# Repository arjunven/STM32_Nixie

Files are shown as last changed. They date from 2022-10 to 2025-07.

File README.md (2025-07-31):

# STM32 and USB-C Based Nixie Clock
A [Nixie](http://en.wikipedia.org/wiki/Nixie_tube) clock that's powered by USB-C and based on a STM32 microcontroller. Designed schematic, layout, and firmware from scratch! Fun mix of retro tech with modern electronics. Main Features:
  - Custom 5V to 180V boost converter that operates in discontinous conduction mode to power the Nixie tubes
  - USB-C Power input + bootloader
  - Push button dial that's used to set time and interface with the menu
  - Used high voltage shift registers to run the tube display
  - STM32F100 micro controller with abysmal flash storage ... because that's all that was in stock during the great covid parts shortage of 2021 when I started this project 

## Mostly Finished Product

 
  - Still would like to add a walnut enclosure and a nice wodden knob for the push button dial
  - 80/20 rule in full force

## Layout




- 4 Layer board

## Schematics
### 5V to 180V Boost Converter


### Full Schematics
[Full Schematics here
](https://github.com/arjunven/STM32_Nixie/blob/main/pcb/outputs/STM32_Nixie_Schematics.pdf
)

## Bringup/Development



- Bring up of HV shift register driver with assistance from Merlin

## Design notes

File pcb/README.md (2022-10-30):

View this project on [CADLAB.io](https://cadlab.io/project/26133). 

# STM32_Nixie
 STM32 based Nixie clock with USB C 5V input.

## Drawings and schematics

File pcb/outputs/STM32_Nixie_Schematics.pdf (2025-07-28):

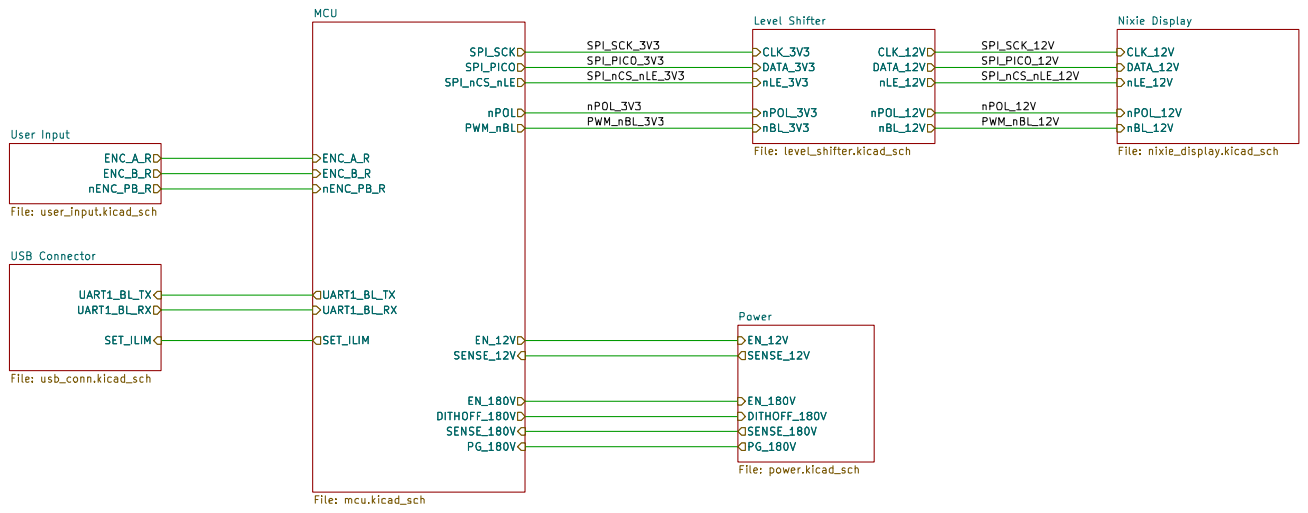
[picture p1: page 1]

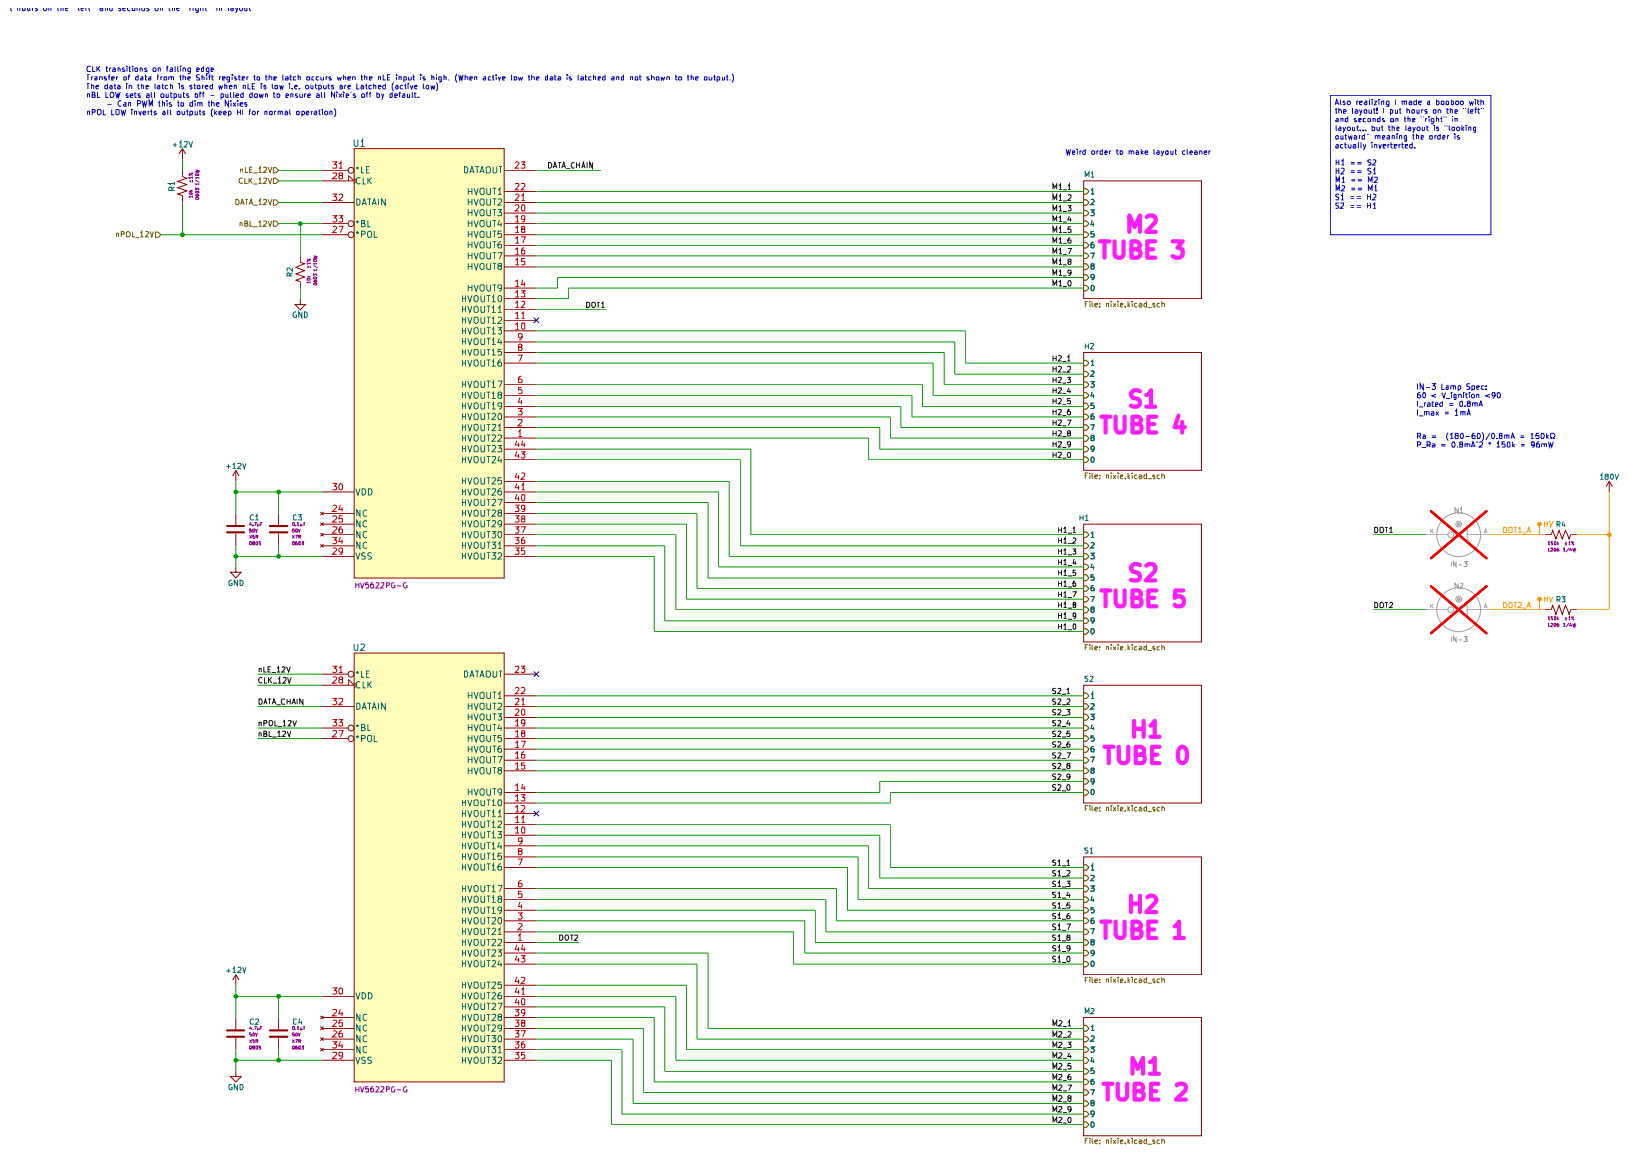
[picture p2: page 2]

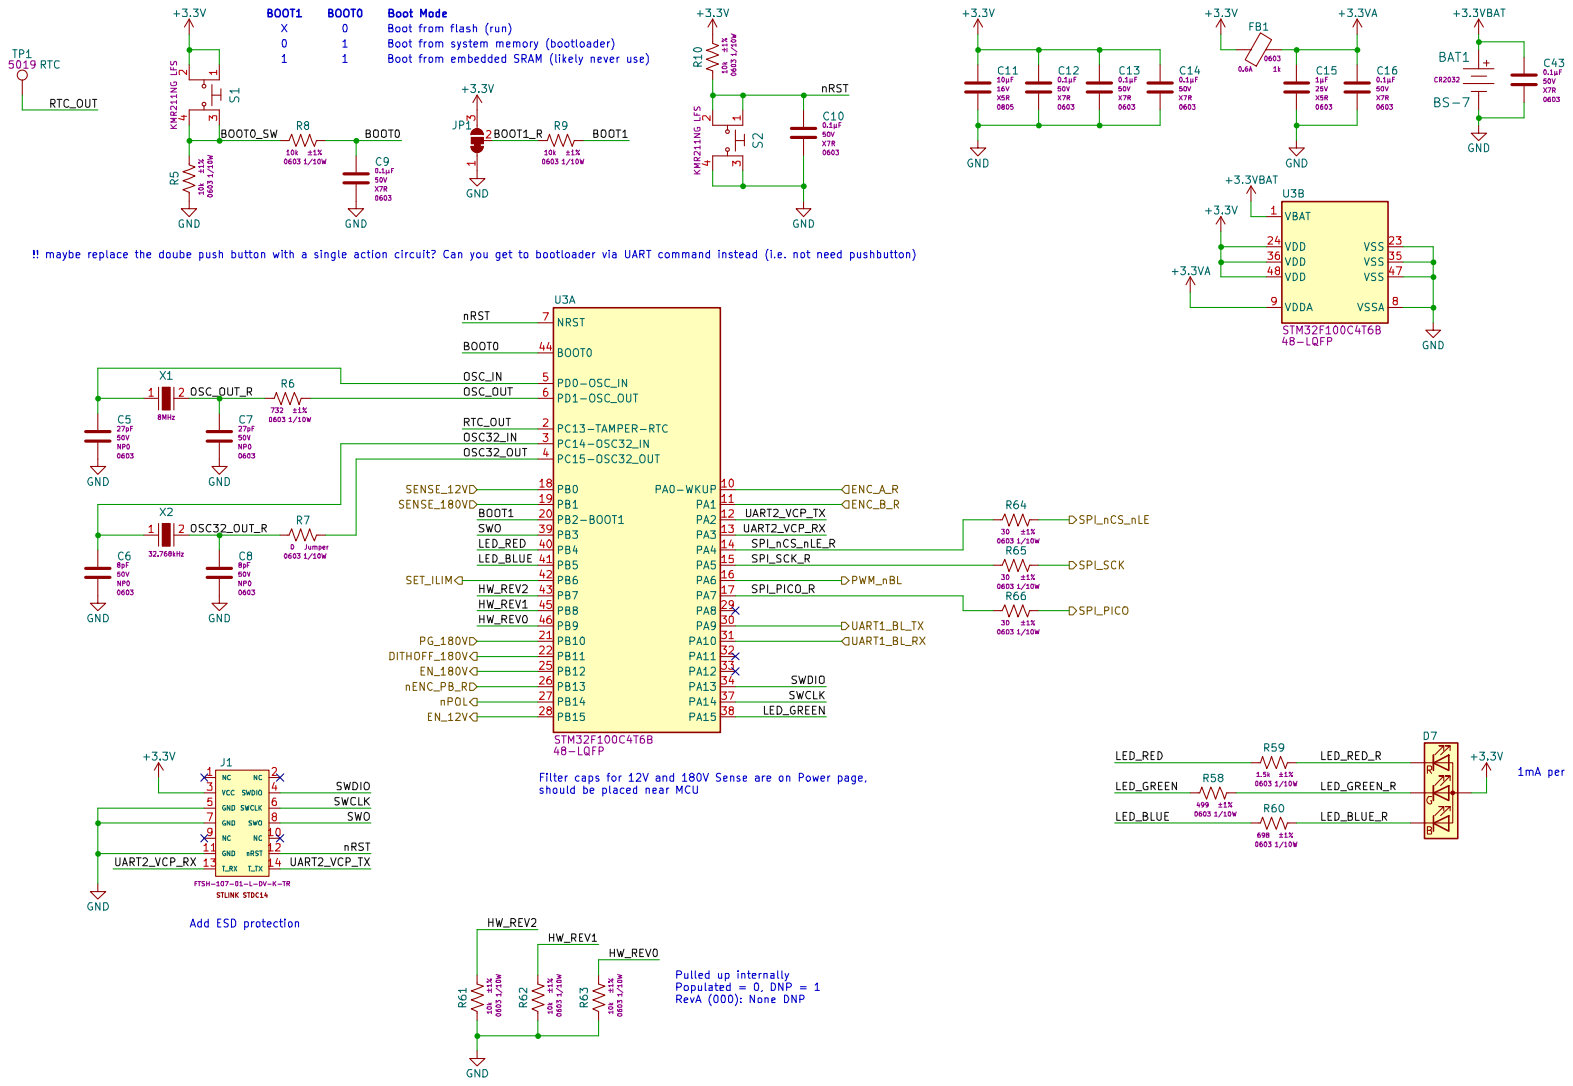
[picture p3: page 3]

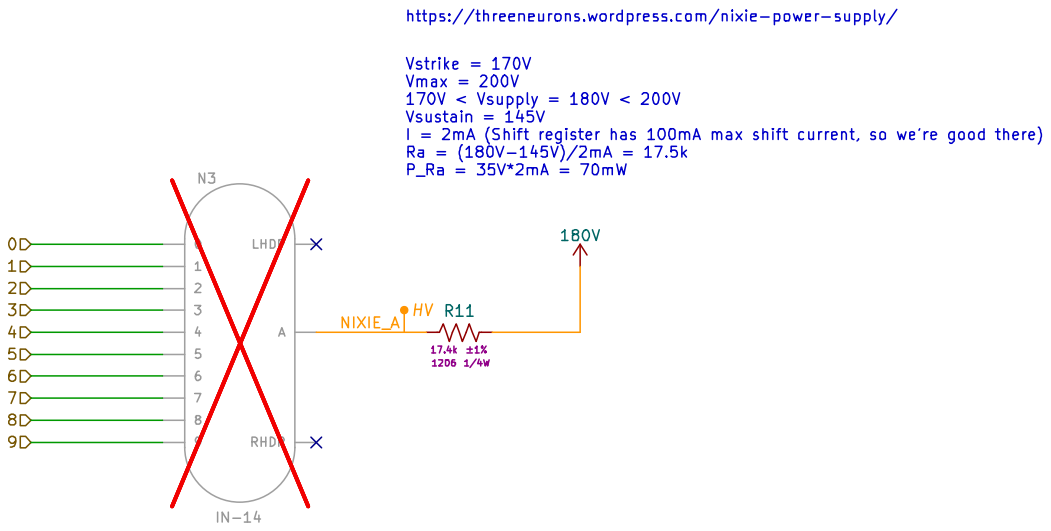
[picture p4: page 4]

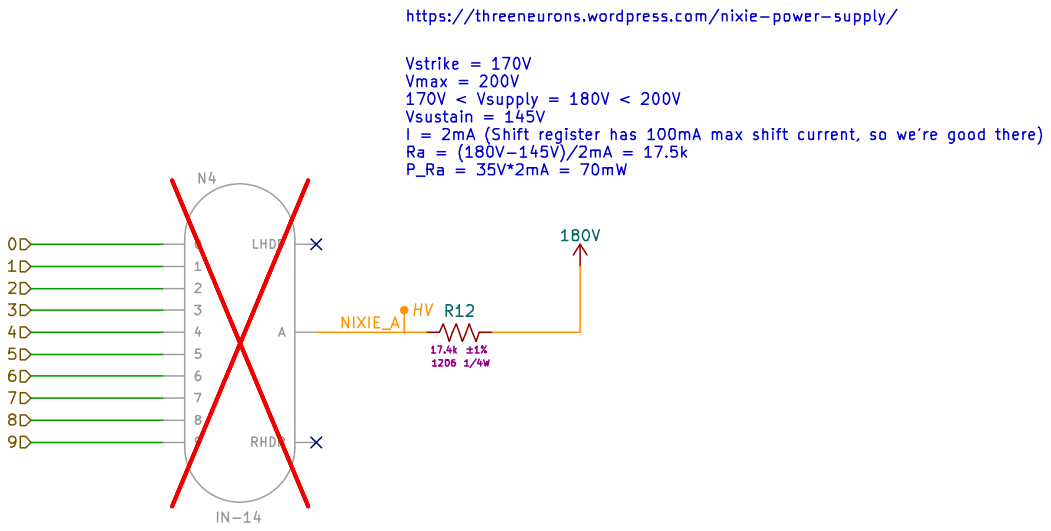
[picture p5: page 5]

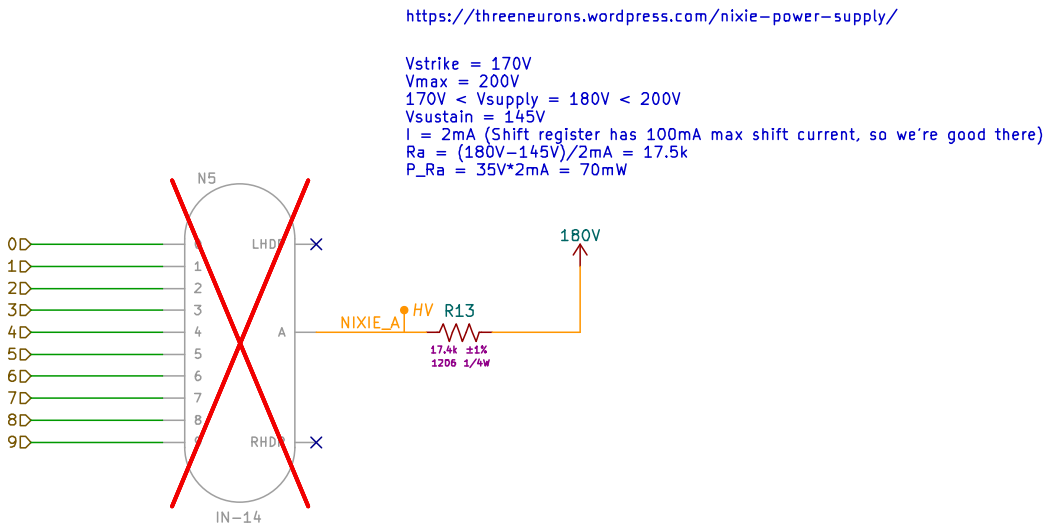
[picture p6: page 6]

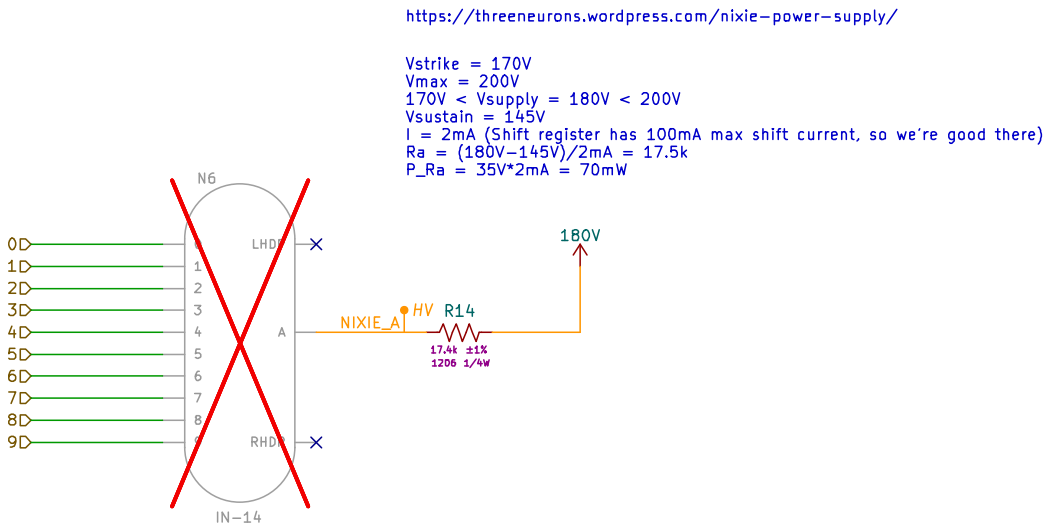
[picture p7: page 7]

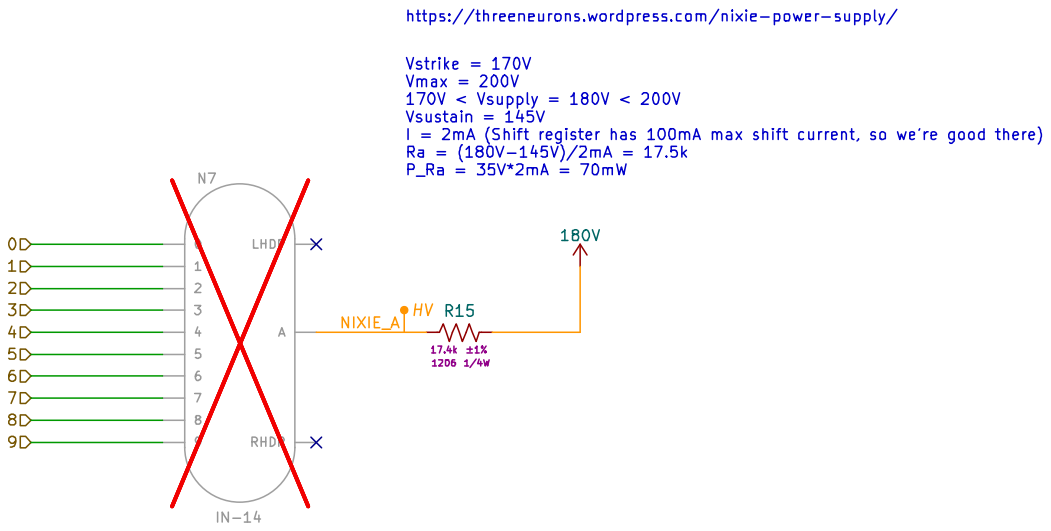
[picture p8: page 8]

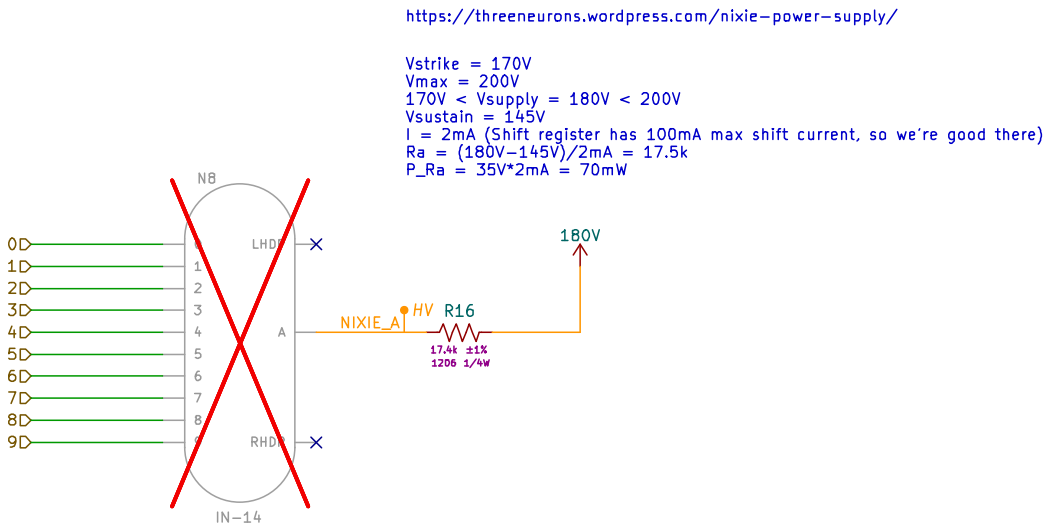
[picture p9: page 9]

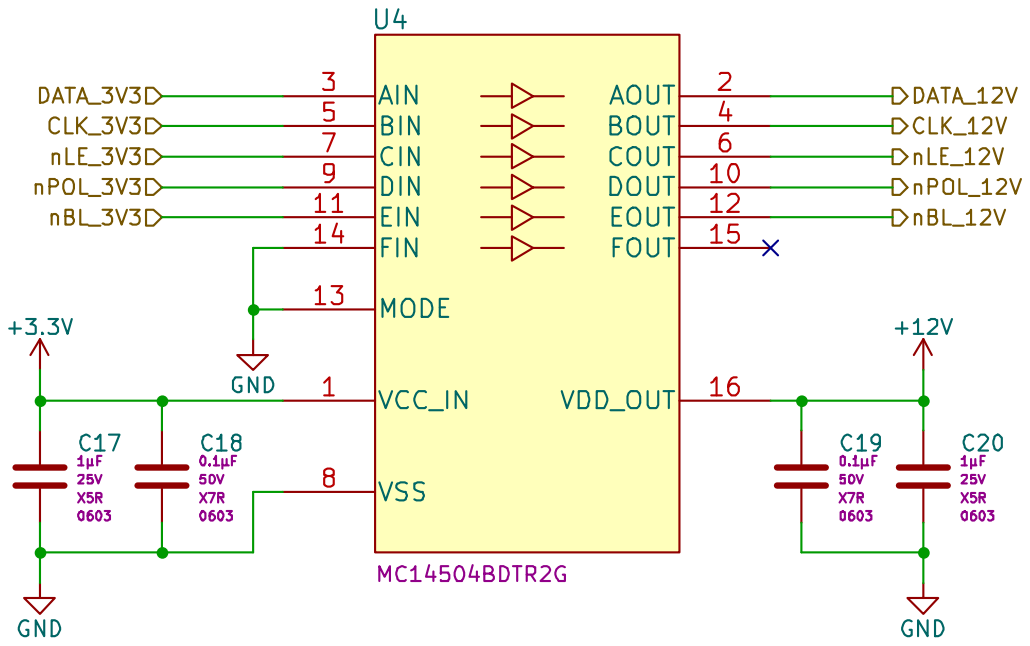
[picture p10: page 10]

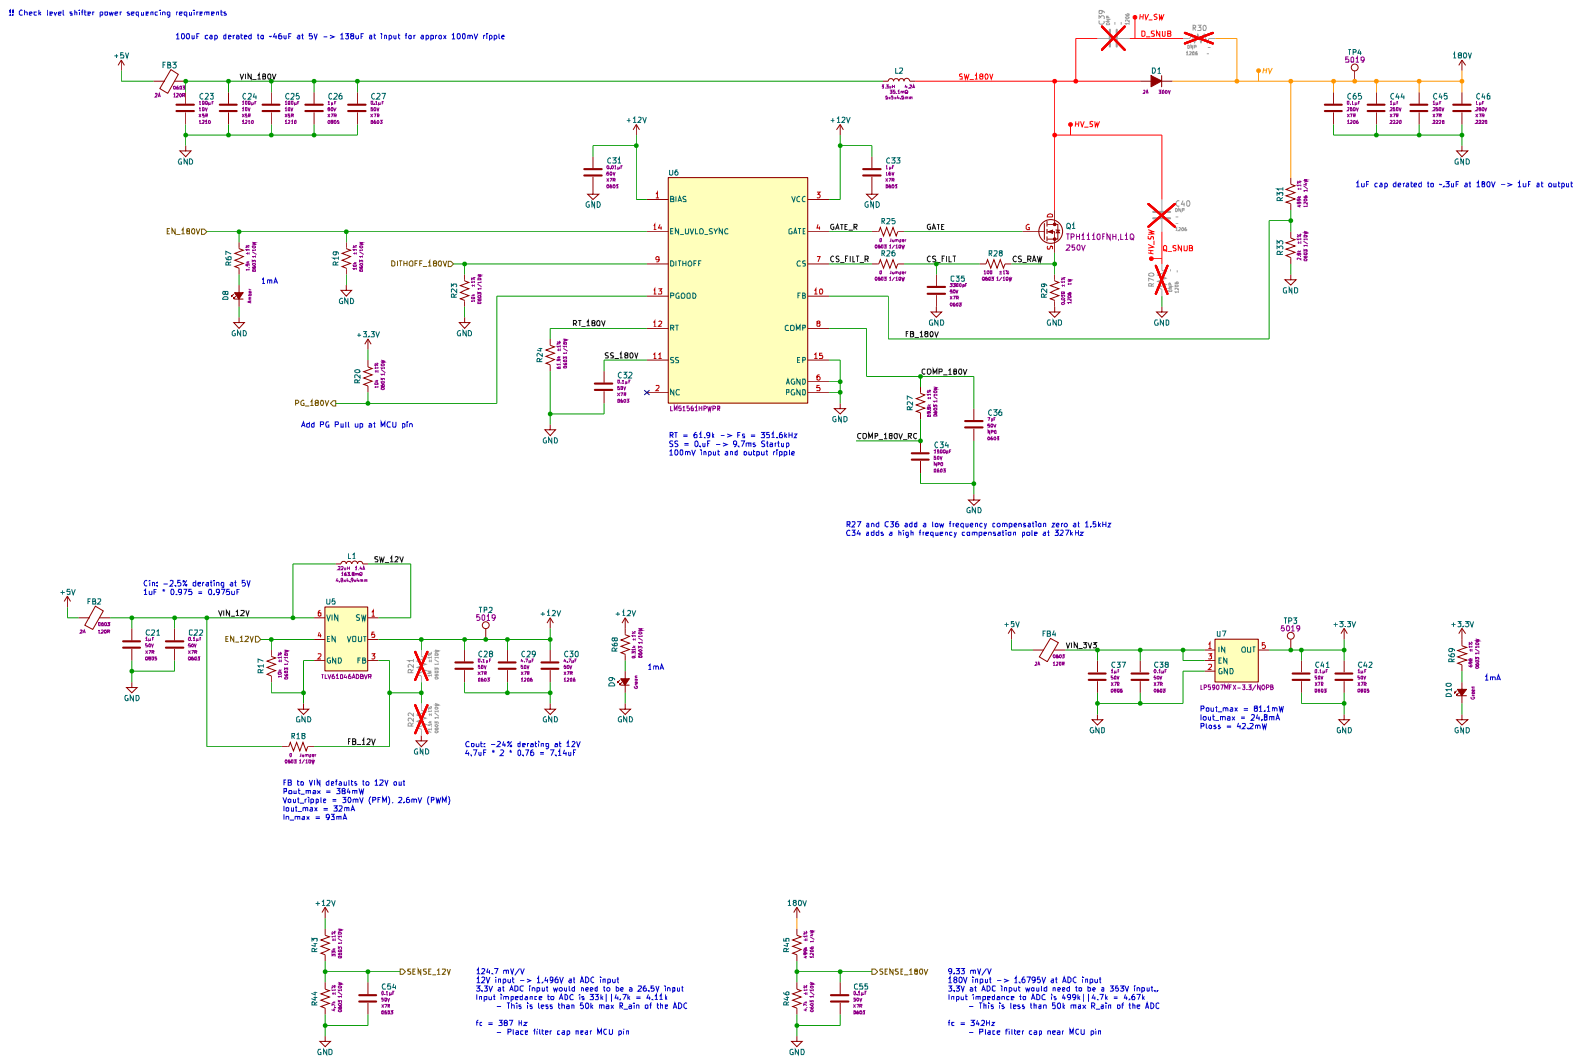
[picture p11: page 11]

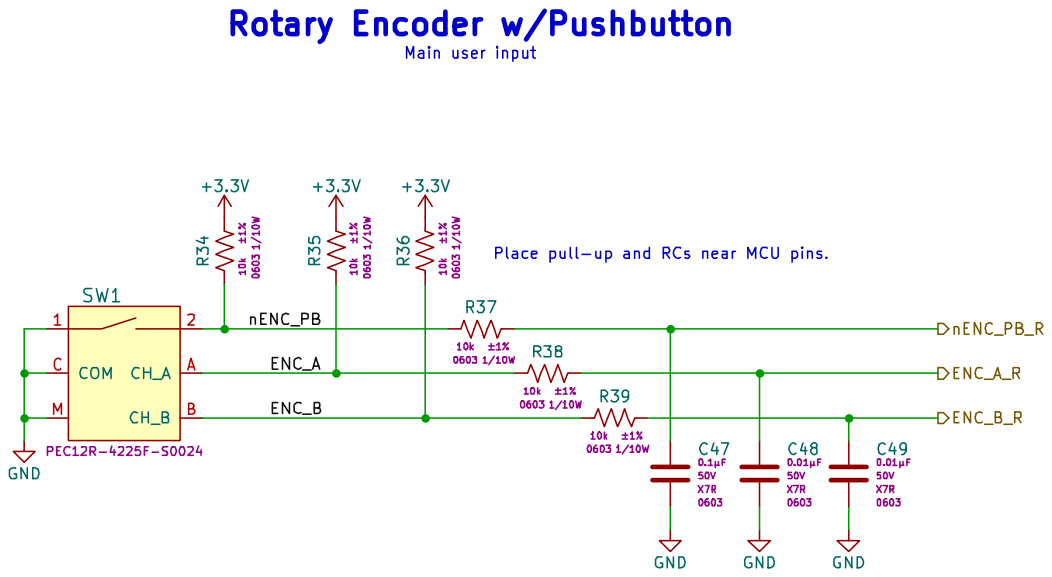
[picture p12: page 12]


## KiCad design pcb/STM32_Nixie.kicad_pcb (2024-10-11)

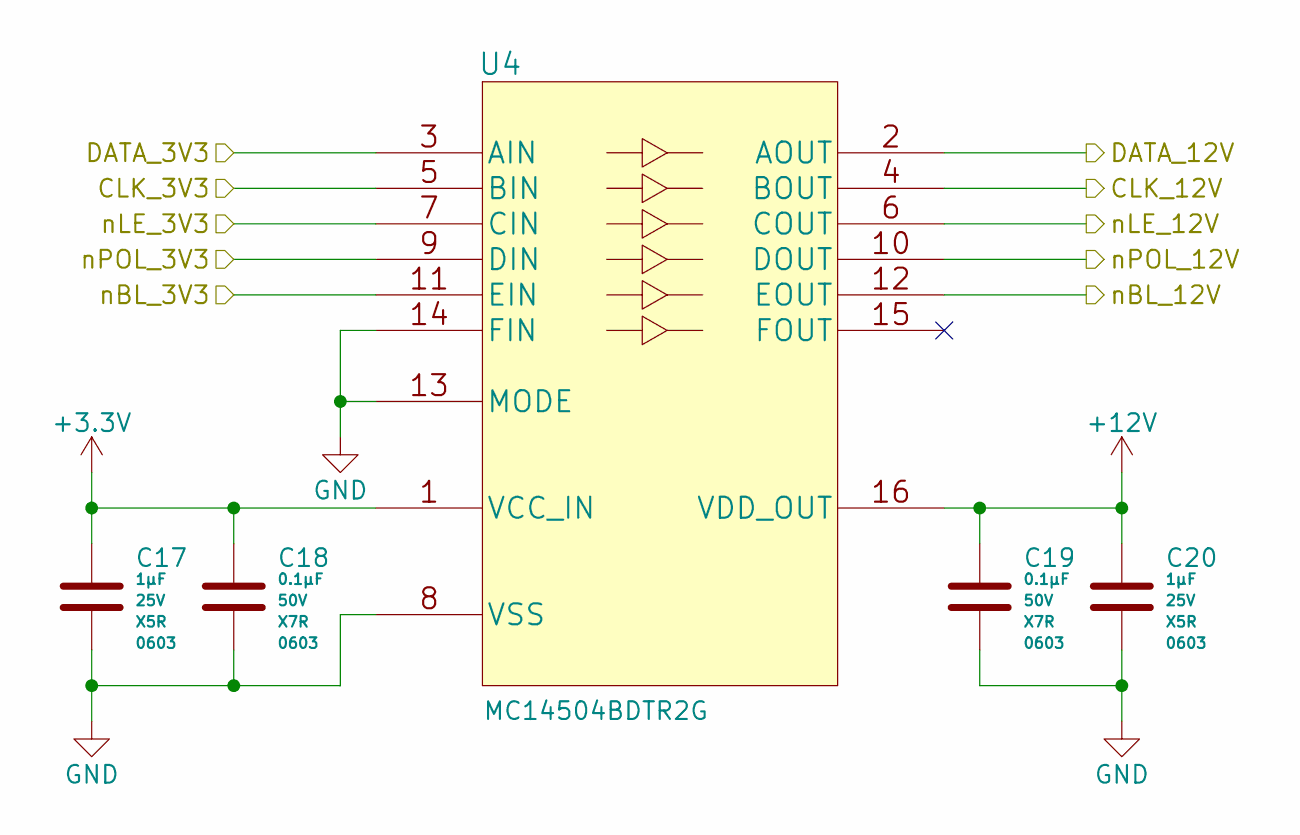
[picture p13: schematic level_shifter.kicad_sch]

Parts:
C17, C20: CAP_CER_1u_25V_X5R_0603; C_0603_1608Metric; Voltage 25V; ManufacturerPN CC0603KRX5R8BB105
C18, C19: CAP_CER_0u1_50V_X7R_0603; C_0603_1608Metric; Voltage 50V; ManufacturerPN CL10B104KB8NNNC
U4: IC_LVL_ONSEMI_MC14504BDTR2G; MC14504BDTR2G; ManufacturerPN MC14504BDTR2G

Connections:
+3.3V: C17.1, C18.1, U4.1 (VCC_IN); also elsewhere on the board
+12V: C19.1, C20.1, U4.16 (VDD_OUT); also elsewhere on the board
/PWM_nBL_3V3: U4.11 (EIN); also elsewhere on the board
/PWM_nBL_12V: U4.12 (EOUT); also elsewhere on the board
/SPI_PICO_3V3: U4.3 (AIN); also elsewhere on the board
/SPI_PICO_12V: U4.2 (AOUT); also elsewhere on the board
/SPI_SCK_3V3: U4.5 (BIN); also elsewhere on the board
/SPI_SCK_12V: U4.4 (BOUT); also elsewhere on the board
/SPI_nCS_nLE_3V3: U4.7 (CIN); also elsewhere on the board
/SPI_nCS_nLE_12V: U4.6 (COUT); also elsewhere on the board
/nPOL_3V3: U4.9 (DIN); also elsewhere on the board
/nPOL_12V: U4.10 (DOUT); also elsewhere on the board
GND: C17.2, C18.2, C19.2, C20.2, U4.8 (VSS), U4.13 (MODE), U4.14 (FIN); also elsewhere on the board

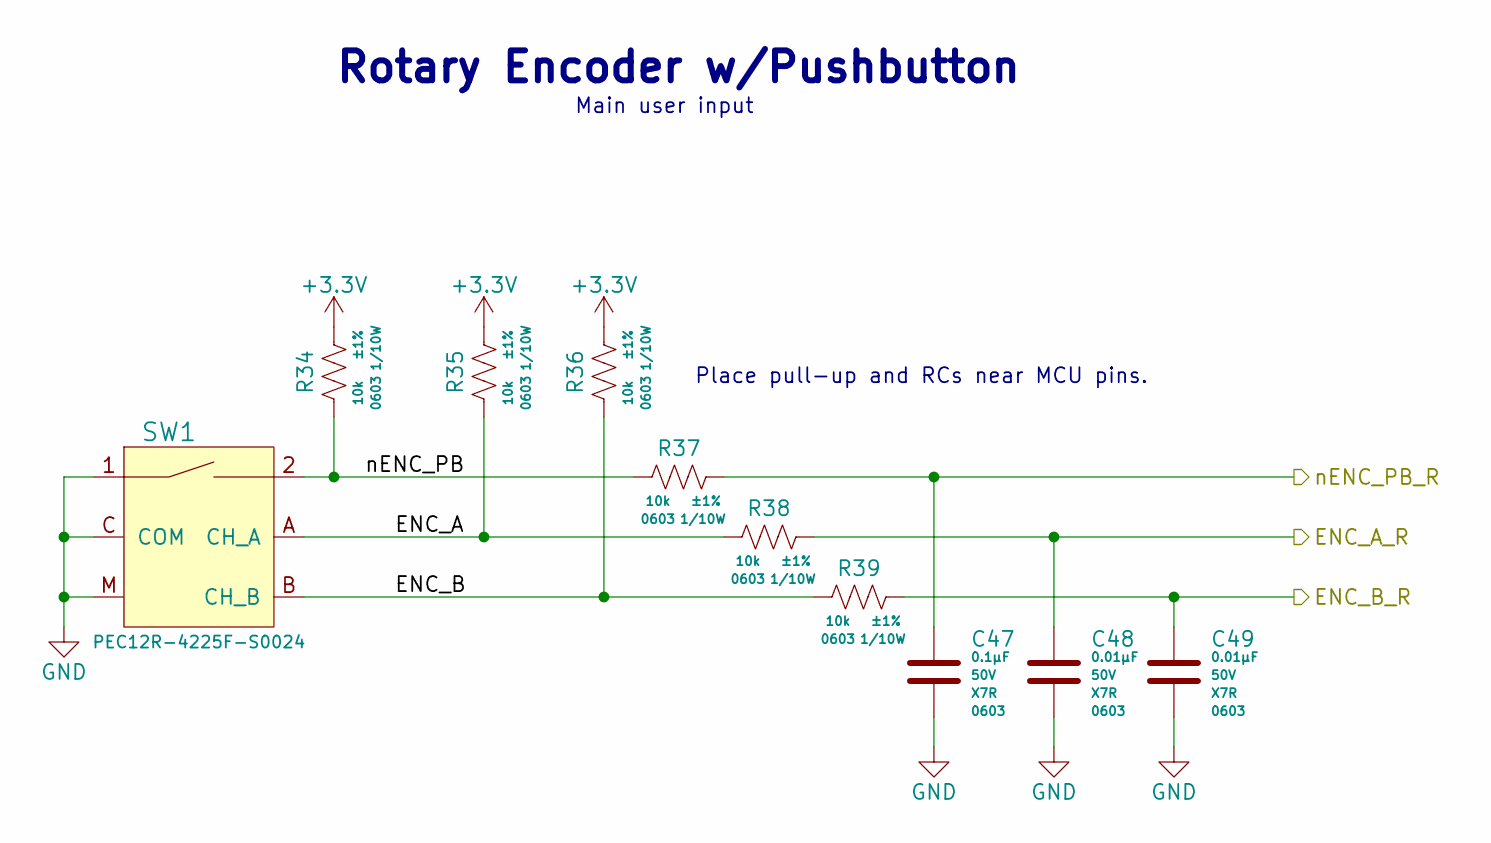
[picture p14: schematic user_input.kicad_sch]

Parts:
C47: CAP_CER_0u1_50V_X7R_0603; C_0603_1608Metric; Voltage 50V; ManufacturerPN CL10B104KB8NNNC
C48, C49: CAP_CER_0u01_50V_X7R_0603; C_0603_1608Metric; Voltage 50V; ManufacturerPN CL10B103KB8NNNC
R34, R35, R36, R37, R38, R39: RES_10K_1P_1/10W_0603; R_0603_1608Metric; Tolerance ±1%; ManufacturerPN RC0603FR-0710KL
SW1: ENC_SPST_24PPR_PEC12R-4225F-S0024; ENC_SPST_PEC12R-4x25F-Sxxx; ManufacturerPN PEC12R-4225F-S0024

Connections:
+3.3V: R34.1, R35.1, R36.1; also elsewhere on the board
/MCU/ENC_A_R: C48.1, R38.1; also elsewhere on the board
/MCU/ENC_B_R: C49.1, R39.1; also elsewhere on the board
/MCU/nENC_PB_R: C47.1, R37.1; also elsewhere on the board
/User Input/ENC_A: R35.2, R38.2, SW1.A (CH_A)
/User Input/ENC_B: R36.2, R39.2, SW1.B (CH_B)
/User Input/nENC_PB: R34.2, R37.2, SW1.2
GND: C47.2, C48.2, C49.2, SW1.1, SW1.C (COM), SW1.M; also elsewhere on the board

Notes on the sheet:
Place pull-up and RCs near MCU pins.
Rotary Encoder w/Pushbutton
Main user input

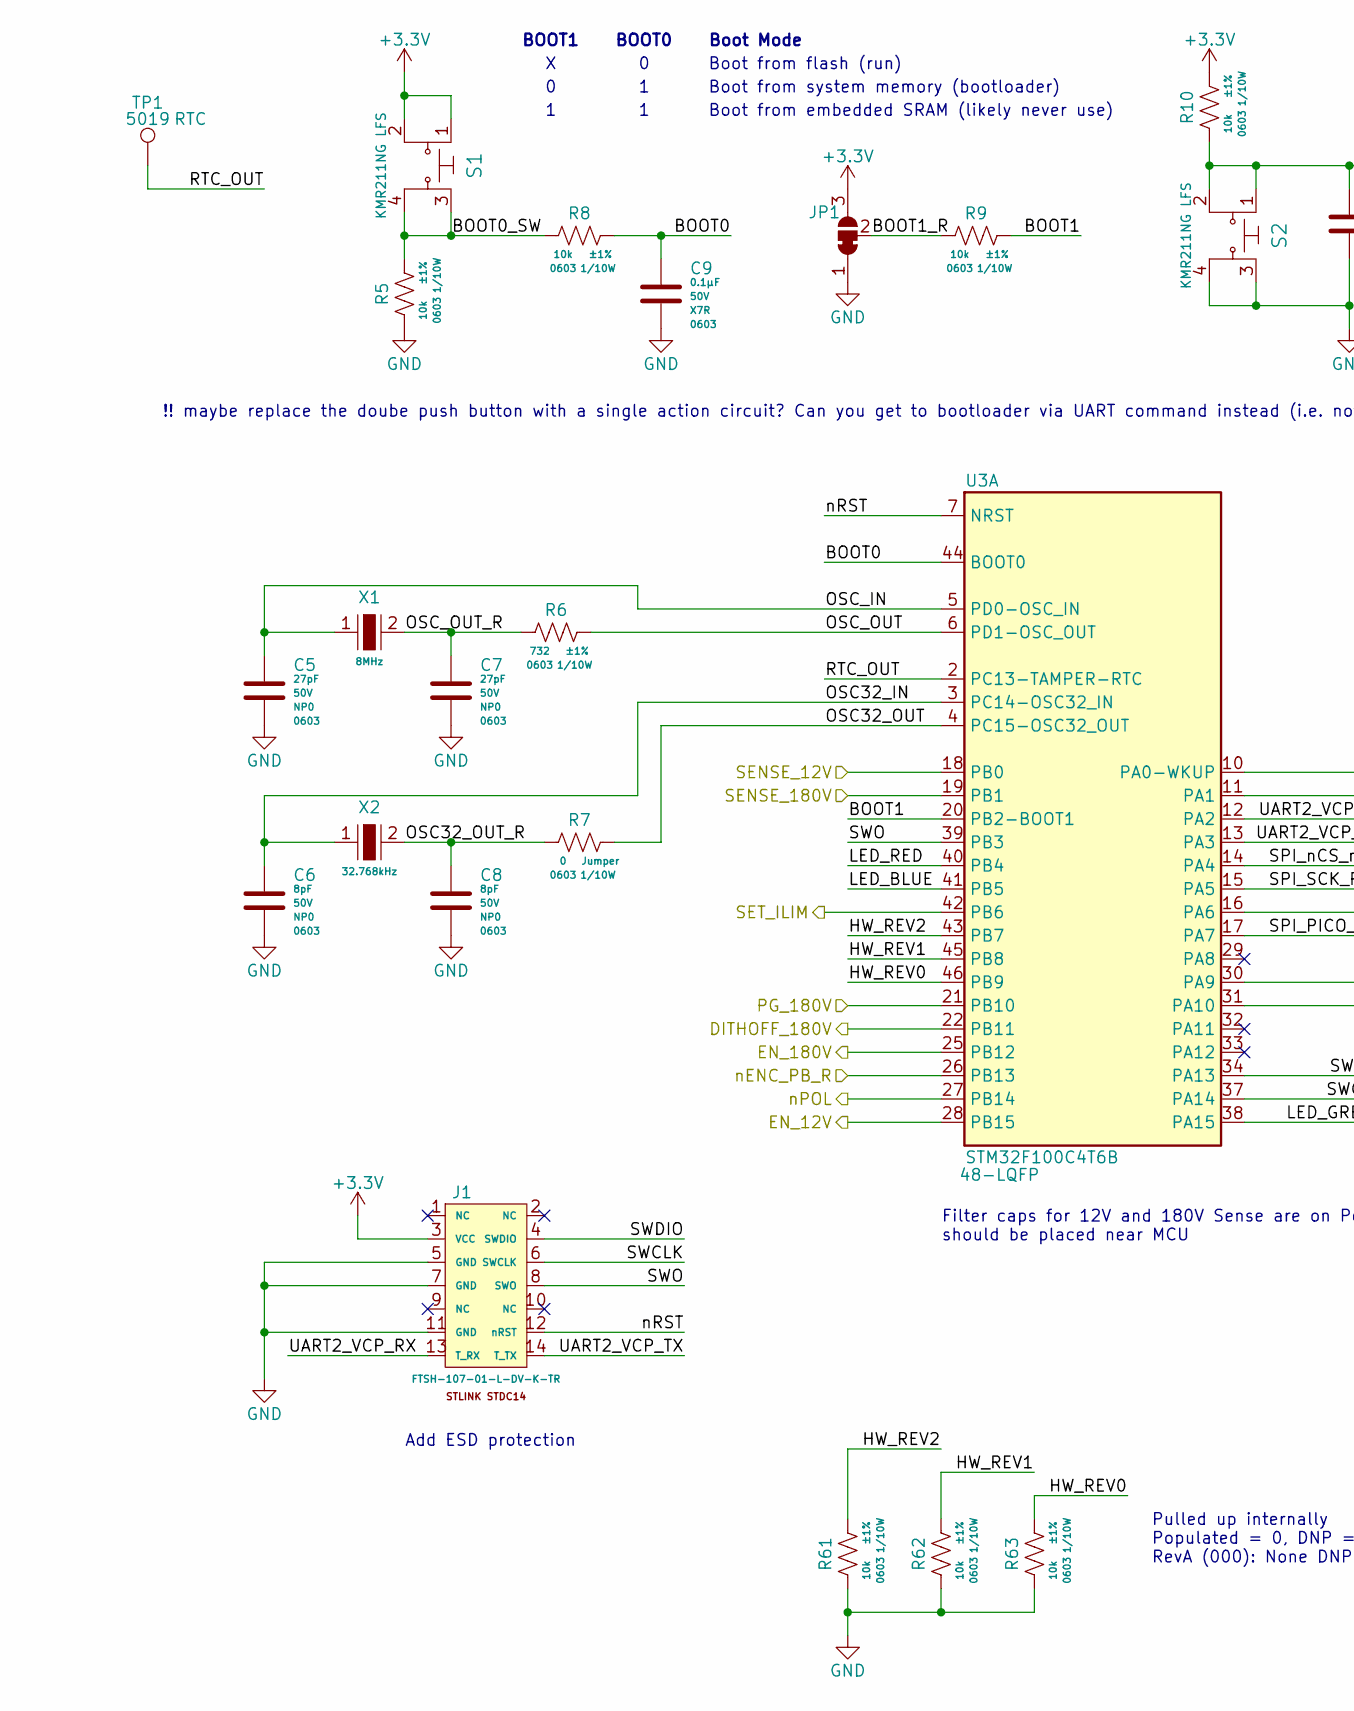
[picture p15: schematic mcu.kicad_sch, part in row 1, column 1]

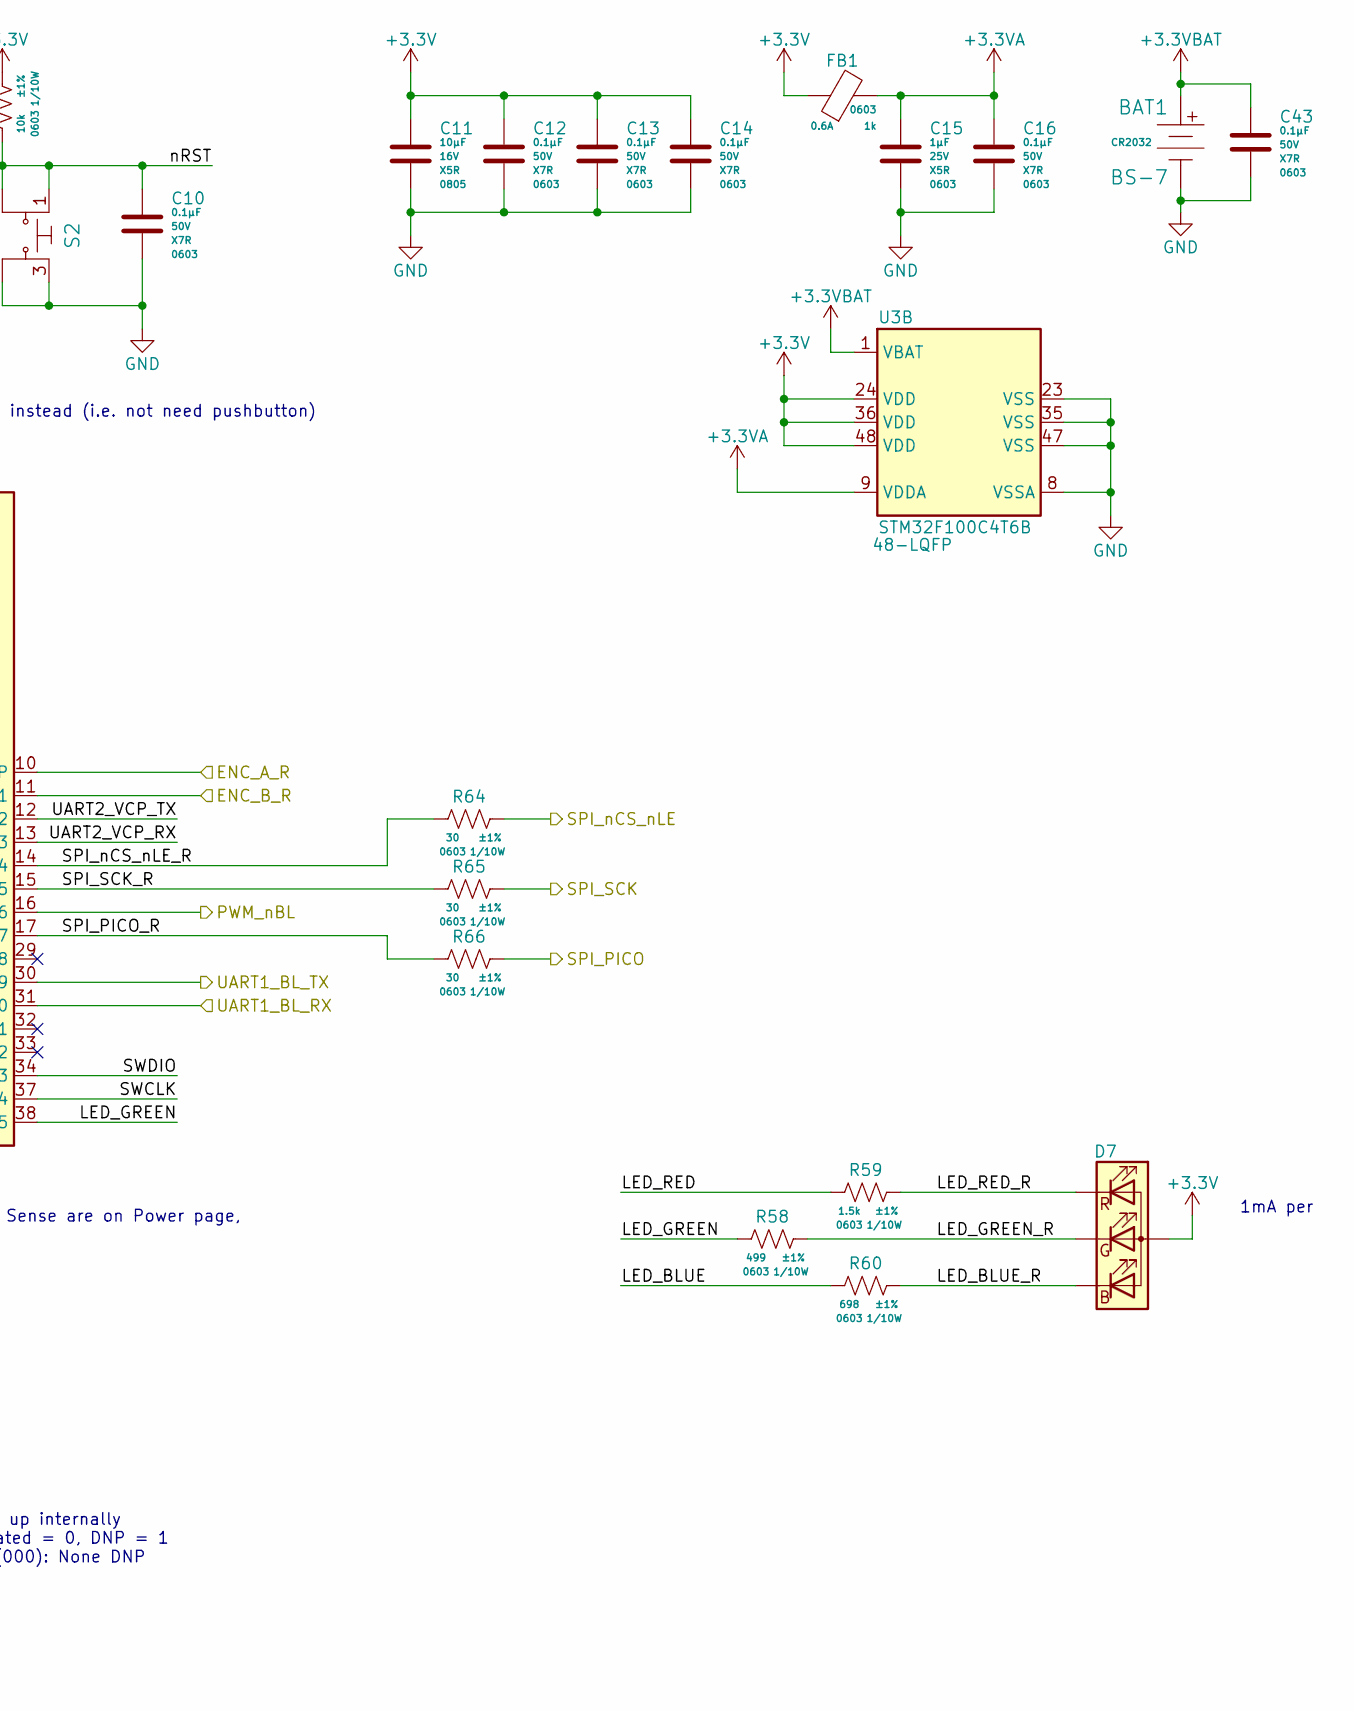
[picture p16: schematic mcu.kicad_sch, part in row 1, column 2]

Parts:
BAT1: BS-7; Battery_Holder_Coin_2032_BS-7; ManufacturerPN BS-7
C5, C7: CAP_CER_27p_50V_NP0_0603; C_0603_1608Metric; Voltage 50V; ManufacturerPN CC0603FRNPO9BN270
C6, C8: CAP_CER_8p_50V_NP0_0603; C_0603_1608Metric; Voltage 50V; ManufacturerPN CBR06C809B5GAC
C9, C10, C12, C13, C14, C16, C43: CAP_CER_0u1_50V_X7R_0603; C_0603_1608Metric; Voltage 50V; ManufacturerPN CL10B104KB8NNNC
C11: CAP_CER_10u_16V_X5R_0805; C_0805_2012Metric; Voltage 16V; ManufacturerPN CL21A106KOQNNNE
C15: CAP_CER_1u_25V_X5R_0603; C_0603_1608Metric; Voltage 25V; ManufacturerPN CC0603KRX5R8BB105
D7: LED_RGB_0606; EAST1616RGBB2_EVE; ManufacturerPN EAST1616RGBB2
FB1: FER_1K_0A6_0603; L_0603_1608Metric; ManufacturerPN 742792662
J1: CON_SAMTEC_14P_2R_1m27_P_KEY_FTSH-107-01-L-DV-K-TR; CON_FTSH-107-01-x-DV-K; ManufacturerPN FTSH-107-01-L-DV-K-TR
JP1: SolderJumper_3_Bridged12; SolderJumper-3_P1.3mm_Bridged12_RoundedPad1.0x1.5mm_NumberL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
R5, R8, R9, R10, R61, R62, R63: RES_10K_1P_1/10W_0603; R_0603_1608Metric; Tolerance ±1%; ManufacturerPN RC0603FR-0710KL
R6: RES_732R_1P_1/10W_0603; R_0603_1608Metric; Tolerance ±1%; ManufacturerPN RC0603FR-07732RL
R7: RES_0R_1/10W_0603; R_0603_1608Metric; Tolerance Jumper; ManufacturerPN RMCF0603ZT0R00
R58: RES_499R_1P_1/10W_0603; R_0603_1608Metric; Tolerance ±1%; ManufacturerPN RC0603FR-07499RL
R59: RES_1K5_1P_1/10W_0603; R_0603_1608Metric; Tolerance ±1%; ManufacturerPN RC0603FR-071K5L
R60: RES_698R_1P_1/10W_0603; R_0603_1608Metric; Tolerance ±1%; ManufacturerPN RC0603FR-07698RL
R64, R65, R66: RES_30R_1P_1/10W_0603; R_0603_1608Metric; Tolerance ±1%; ManufacturerPN RC0603FR-0730RL
S1, S2: SW_TACT_KMR211NG LFS; SW_Push_1P1T_NO_CK_KMR2; ManufacturerPN KMR211NG LFS
TP1: RTC; TestPoint_Keystone_5019_Minature; ManufacturerPN 5019
U3: IC_MCU_STM32F100C4T6B_48LQFP; LQFP-48_7x7mm_P0.5mm; ManufacturerPN STM32F100C4T6B
X1: XTAL_8M_20PPM_18pF_ECS-80-18-30-JGN-TR; SMD-2_5x3.2mm_ECS; Frequency Tolerance 20ppm; ManufacturerPN ECS-80-18-30-JGN-TR
X2: XTAL_32K768_10PPM_7pF_ECS-.327-7-34B-C-TR; SMD-2_3.2x1.5mm_ECS; Frequency Tolerance 10ppm; ManufacturerPN ECS-.327-7-34B-C-TR

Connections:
+3.3V: C11.1, C12.1, C13.1, C14.1, D7.4 (A), FB1.1, J1.3 (VCC), JP1.3 (B), R10.1, S1.1, S1.2, U3.24 (VDD), U3.36 (VDD), U3.48 (VDD); also elsewhere on the board
+3.3VA: C15.1, C16.1, FB1.2, U3.9 (VDDA)
+3.3VBAT: BAT1.Pos, C43.1, U3.1 (VBAT)
/MCU/BOOT0: C9.1, R8.1, U3.44 (BOOT0)
/MCU/BOOT0_SW: R5.1, R8.2, S1.3, S1.4
/MCU/BOOT1: R9.1, U3.20 (PB2-BOOT1)
/MCU/BOOT1_R: JP1.2 (C), R9.2
/MCU/DITHOFF_180V: U3.22 (PB11); also elsewhere on the board
/MCU/ENC_A_R: U3.10 (PA0-WKUP); also elsewhere on the board
/MCU/ENC_B_R: U3.11 (PA1); also elsewhere on the board
/MCU/EN_12V: U3.28 (PB15); also elsewhere on the board
/MCU/EN_180V: U3.25 (PB12); also elsewhere on the board
/MCU/HW_REV0: R63.1, U3.46 (PB9)
/MCU/HW_REV1: R62.1, U3.45 (PB8)
/MCU/HW_REV2: R61.1, U3.43 (PB7)
/MCU/LED_BLUE: R60.2, U3.41 (PB5)
/MCU/LED_BLUE_R: D7.3 (BK), R60.1
/MCU/LED_GREEN: R58.2, U3.38 (PA15)
/MCU/LED_GREEN_R: D7.2 (GK), R58.1
/MCU/LED_RED: R59.2, U3.40 (PB4)
/MCU/LED_RED_R: D7.1 (RK), R59.1
/MCU/OSC32_IN: C6.1, U3.3 (PC14-OSC32_IN), X2.1
/MCU/OSC32_OUT: R7.1, U3.4 (PC15-OSC32_OUT)
/MCU/OSC32_OUT_R: C8.1, R7.2, X2.2
/MCU/OSC_IN: C5.1, U3.5 (PD0-OSC_IN), X1.1
/MCU/OSC_OUT: R6.1, U3.6 (PD1-OSC_OUT)
/MCU/OSC_OUT_R: C7.1, R6.2, X1.2
/MCU/PG_180V: U3.21 (PB10); also elsewhere on the board
/MCU/RTC_OUT: TP1.1, U3.2 (PC13-TAMPER-RTC)
/MCU/SENSE_12V: U3.18 (PB0); also elsewhere on the board
/MCU/SENSE_180V: U3.19 (PB1); also elsewhere on the board
/MCU/SET_ILIM: U3.42 (PB6); also elsewhere on the board
/MCU/SPI_PICO_R: R66.2, U3.17 (PA7)
/MCU/SPI_SCK_R: R65.2, U3.15 (PA5)
/MCU/SPI_nCS_nLE_R: R64.2, U3.14 (PA4)
/MCU/SWCLK: J1.6 (SWCLK), U3.37 (PA14)
/MCU/SWDIO: J1.4 (SWDIO), U3.34 (PA13)
/MCU/SWO: J1.8 (SWO), U3.39 (PB3)
/MCU/UART1_BL_RX: U3.31 (PA10); also elsewhere on the board
/MCU/UART1_BL_TX: U3.30 (PA9); also elsewhere on the board
/MCU/UART2_VCP_RX: J1.13 (T_RX), U3.13 (PA3)
/MCU/UART2_VCP_TX: J1.14 (T_TX), U3.12 (PA2)
/MCU/nENC_PB_R: U3.26 (PB13); also elsewhere on the board
/MCU/nRST: C10.1, J1.12 (nRST), R10.2, S2.1, S2.2, U3.7 (NRST)
/PWM_nBL_3V3: U3.16 (PA6); also elsewhere on the board
/SPI_PICO_3V3: R66.1; also elsewhere on the board
/SPI_SCK_3V3: R65.1; also elsewhere on the board
/SPI_nCS_nLE_3V3: R64.1; also elsewhere on the board
/nPOL_3V3: U3.27 (PB14); also elsewhere on the board
GND: BAT1.Neg, C5.2, C6.2, C7.2, C8.2, C9.2, C10.2, C11.2, C12.2, C13.2, C14.2, C15.2, C16.2, C43.2, J1.5 (GND), J1.7 (GND), J1.11 (GND), JP1.1 (A), R5.2, R61.2, R62.2, R63.2, S2.3, S2.4, U3.8 (VSSA), U3.23 (VSS), U3.35 (VSS), U3.47 (VSS); also elsewhere on the board

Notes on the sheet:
Boot from flash (run)
!! maybe replace the doube push button with a single action circuit? Can you get to bootloader via UART command instead (i.e. not need pushbutton)
Boot from system memory (bootloader)
1mA per
Add ESD protection
Filter caps for 12V and 180V Sense are on Power page, should be placed near MCU
Boot Mode
BOOT1
Pulled up internally Populated = 0, DNP = 1 RevA (000): None DNP
BOOT0
Boot from embedded SRAM (likely never use)

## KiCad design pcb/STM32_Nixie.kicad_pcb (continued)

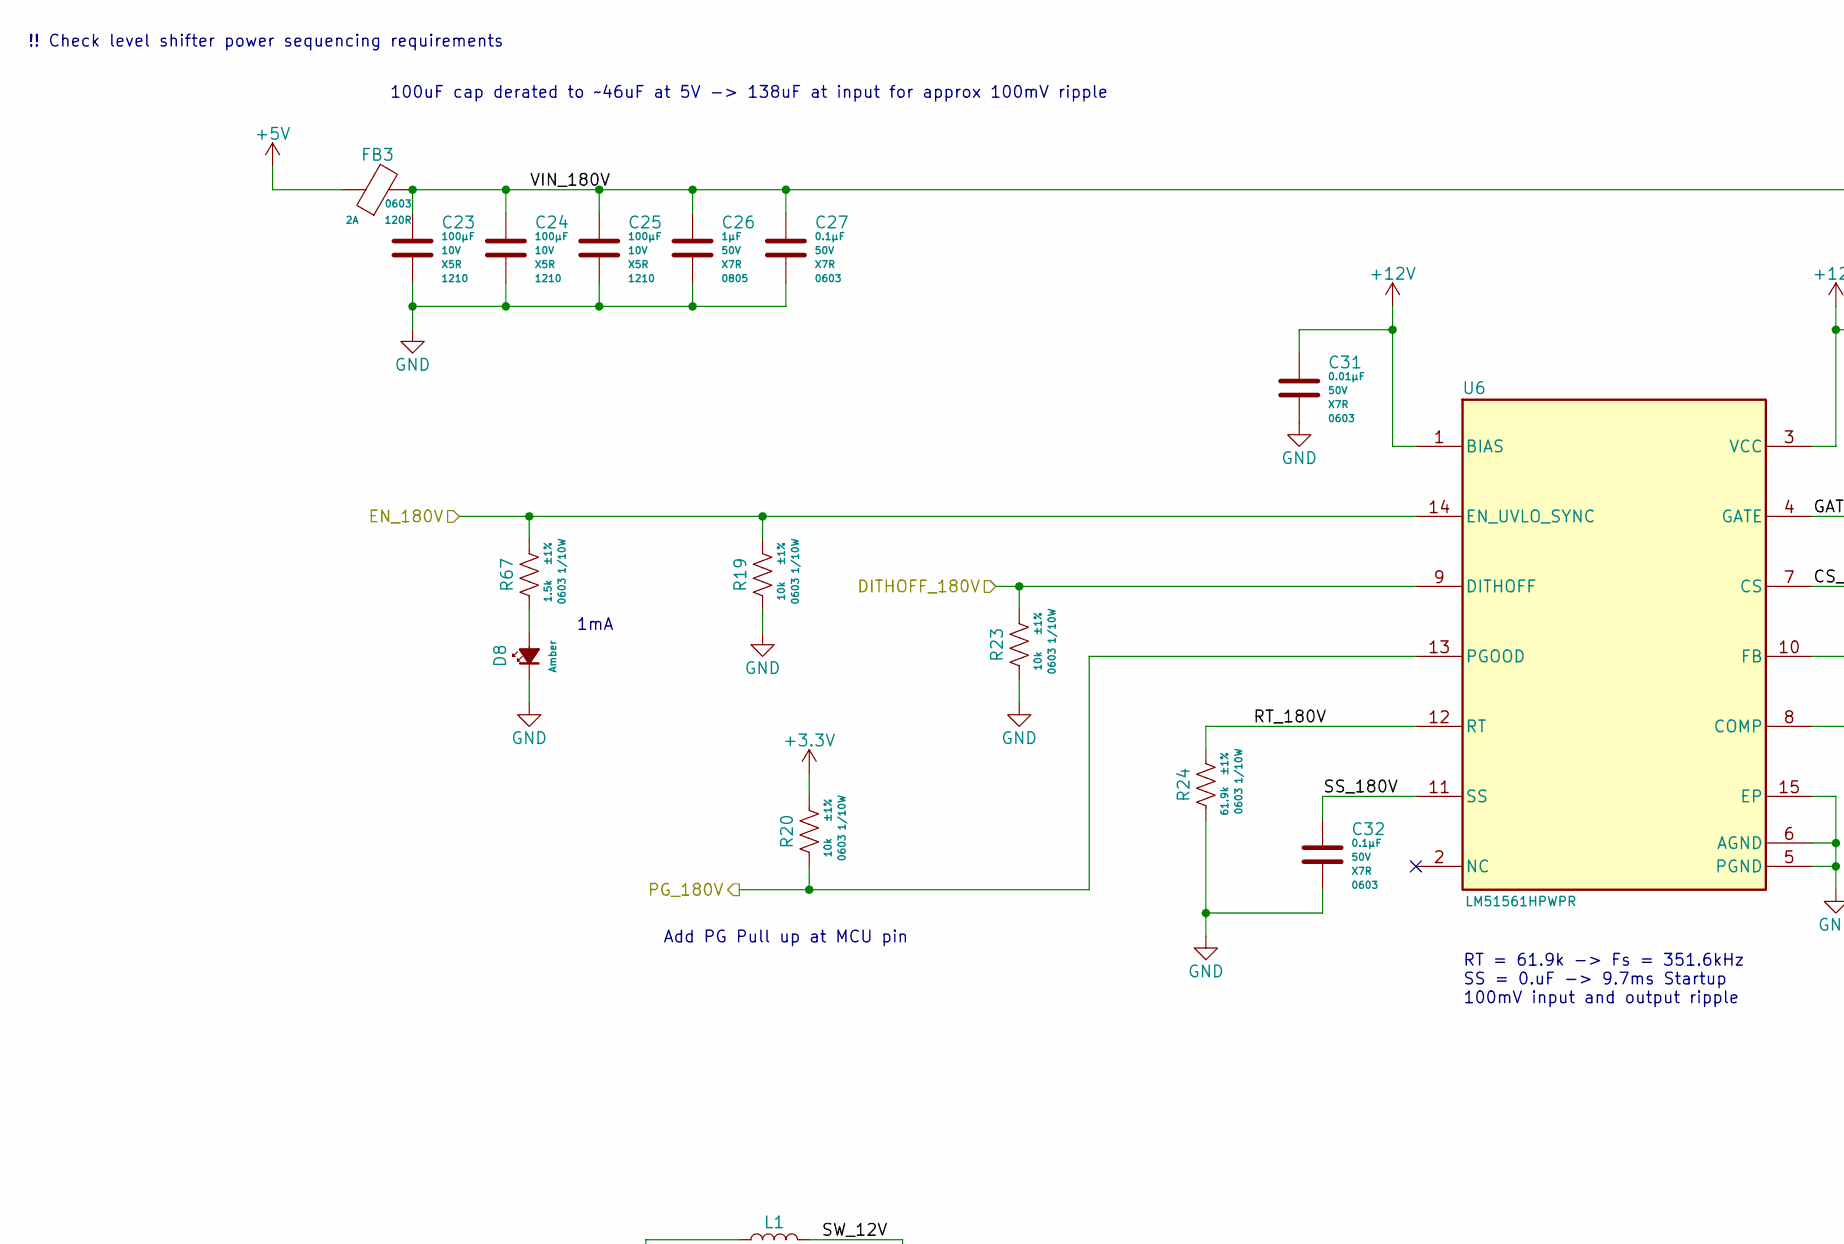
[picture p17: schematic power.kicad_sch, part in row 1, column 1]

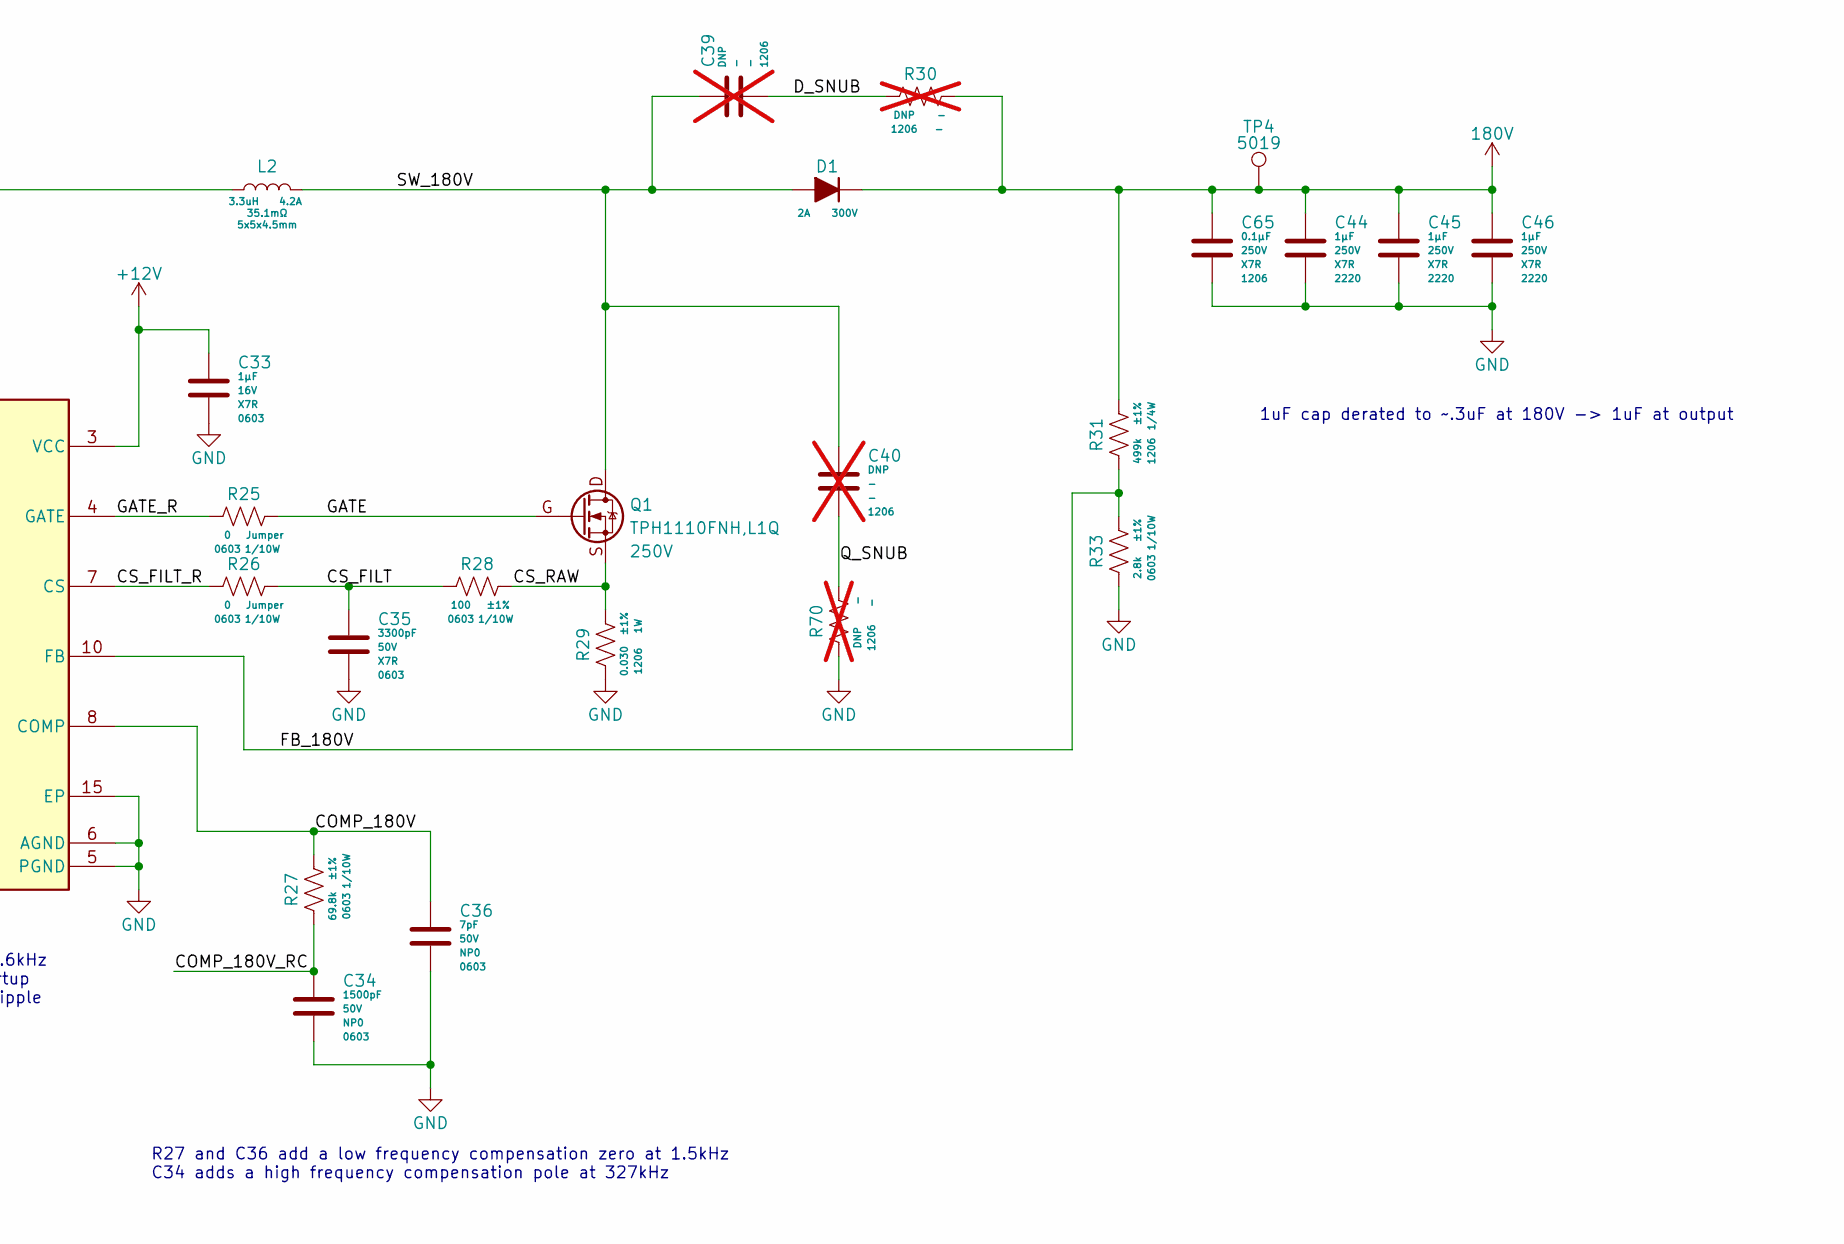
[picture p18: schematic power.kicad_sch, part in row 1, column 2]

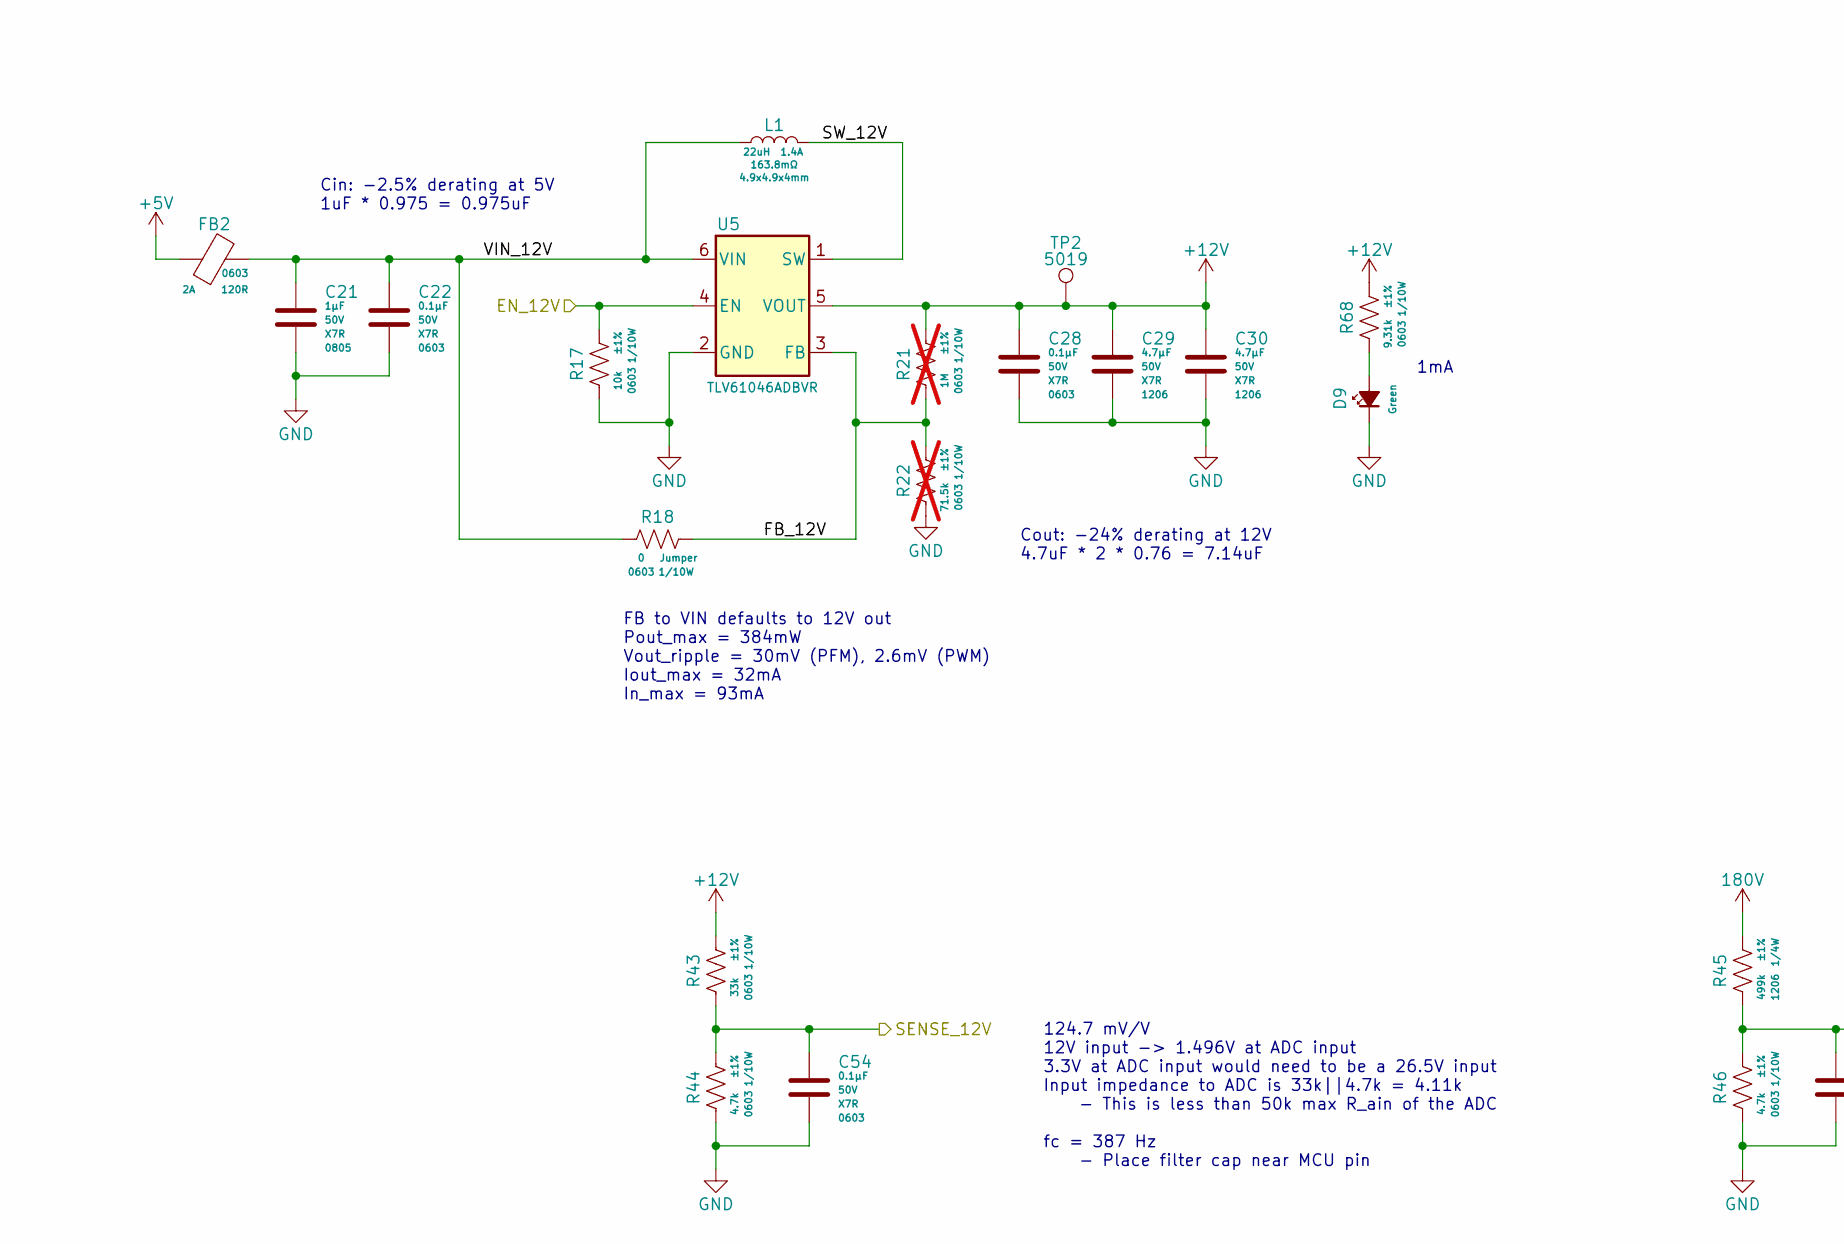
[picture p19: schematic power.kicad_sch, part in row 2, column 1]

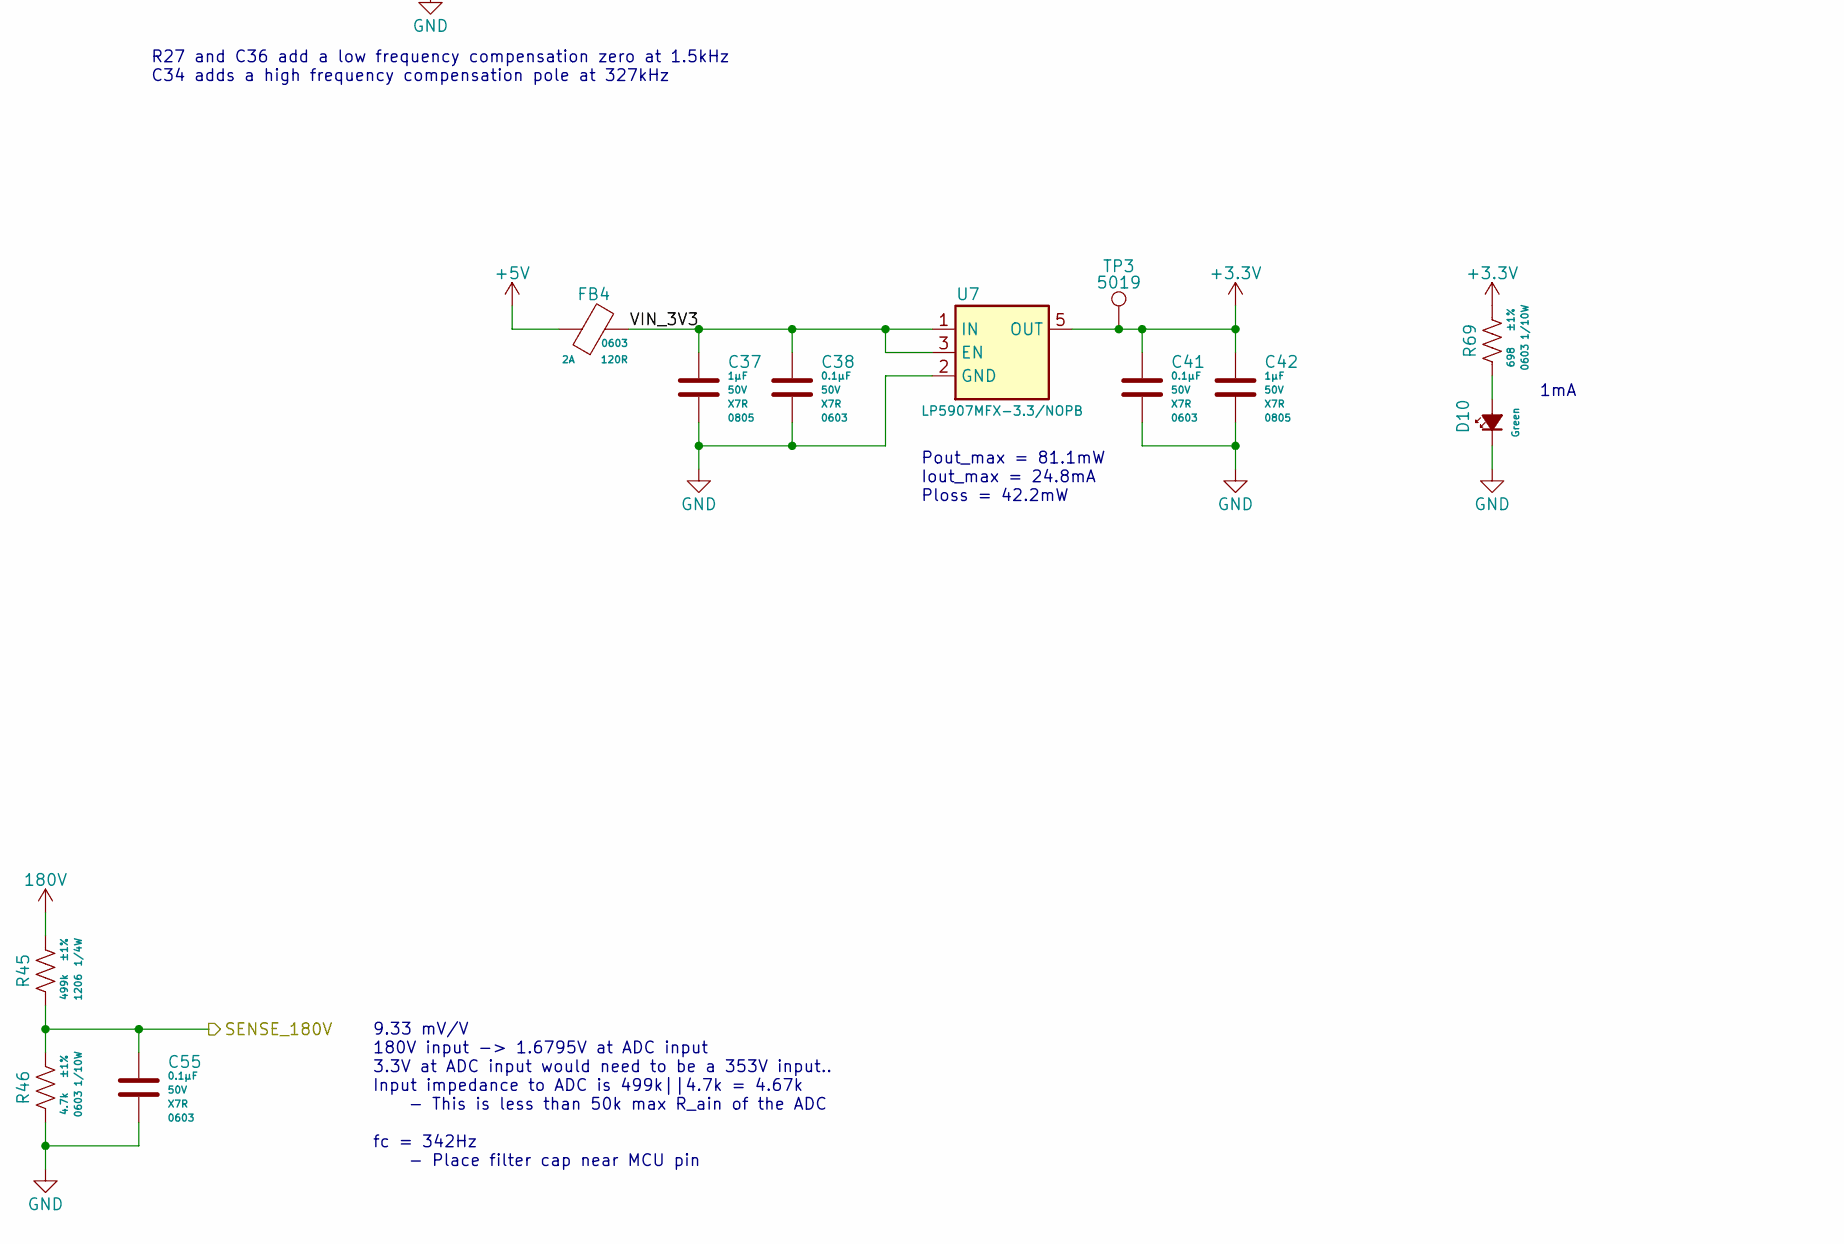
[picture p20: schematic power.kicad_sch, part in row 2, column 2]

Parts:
C21, C26, C37, C42: CAP_CER_1u_50V_X7R_0805; C_0805_2012Metric; Voltage 50V; ManufacturerPN CL21B105KBFNNNE
C22, C27, C28, C32, C38, C41, C54, C55: CAP_CER_0u1_50V_X7R_0603; C_0603_1608Metric; Voltage 50V; ManufacturerPN CL10B104KB8NNNC
C23, C24, C25: CAP_CER_100u_10V_X5R_1210; C_1210_3225Metric; Voltage 10V; ManufacturerPN GRM32ER61A107ME20L
C29, C30: CAP_CER_4u7_50V_X7R_1206; C_1206_3216Metric; Voltage 50V; ManufacturerPN CL31B475KBHNFNE
C31: CAP_CER_0u01_50V_X7R_0603; C_0603_1608Metric; Voltage 50V; ManufacturerPN CL10B103KB8NNNC
C33: CAP_CER_1u_16V_X7R_0603; C_0603_1608Metric; Voltage 16V; ManufacturerPN CC0603KRX7R7BB105
C34: CAP_CER_1500p_50V_NP0_0603; C_0603_1608Metric; Voltage 50V; ManufacturerPN GRM1885C1H152JA01D
C35: CAP_CER_3300p_50V_X7R_0603; C_0603_1608Metric; Voltage 50V; ManufacturerPN CL10B332KB8NNNC
C36: CAP_CER_7p_50V_NP0_0603; C_0603_1608Metric; Voltage 50V; ManufacturerPN CL10C070CB8NNNC
C39, C40: CAP_CER_DNP_1206; C_1206_3216Metric; ManufacturerPN DNP; not fitted
C44, C45, C46: CAP_CER_1u_250V_X7R_2220; C_2220_5750Metric; Voltage 250V; ManufacturerPN C5750X7R2E105K230KA
C65: CAP_CER_0u1_250V_X7R_1206; C_1206_3216Metric; Voltage 250V; ManufacturerPN CL31B104KEHSFNE
D1: D_300V_2A_SMB; D_SMB; ManufacturerPN ES2GHE3_A/H
D8: LED_AMBER_0603; LED_0603_1608Metric; ManufacturerPN 150060AS75000
D9, D10: LED_GREEN_0603; LED_0603_1608Metric; ManufacturerPN 150060GS75000
FB2, FB3, FB4: FER_120R_2A_0603; L_0603_1608Metric; ManufacturerPN BLM18PG121SH1D
L1: IND_22u_1A4_163m8R_4r9x4r9x4; IND_Taiyo-Yuden_NR-50xx; ManufacturerPN NRS5040T220MMGK
L2: IND_3u3_4A2_35m1R_5x5x4r5; IND_VLS5045EX-3R3N; ManufacturerPN VLS5045EX-3R3N
Q1: NFET_250V_10A_TPH1110FNH,L1Q; SOP Advance_TOS; ManufacturerPN TPH1110FNH,L1Q
R17, R19, R20, R23: RES_10K_1P_1/10W_0603; R_0603_1608Metric; Tolerance ±1%; ManufacturerPN RC0603FR-0710KL
R18, R25, R26: RES_0R_1/10W_0603; R_0603_1608Metric; Tolerance Jumper; ManufacturerPN RMCF0603ZT0R00
R21: RES_1M_1P_1/10W_0603; R_0603_1608Metric; Tolerance ±1%; ManufacturerPN RMCF0603FT1M00; not fitted
R22: RES_71K5_1P_1/10W_0603; R_0603_1608Metric; Tolerance ±1%; ManufacturerPN ERJ-3EKF7152V; not fitted
R24: RES_61K9_1P_1/10W_0603; R_0603_1608Metric; Tolerance ±1%; ManufacturerPN ERJ-3EKF6192V
R27: RES_69K8_1P_1/10W_0603; R_0603_1608Metric; Tolerance ±1%; ManufacturerPN RC0603FR-0769K8L
R28: RES_100R_1P_1/10W_0603; R_0603_1608Metric; Tolerance ±1%; ManufacturerPN ERJ-3EKF1000V
R29: RES_R030_1P_1W_1206; R_1206_3216Metric; Tolerance ±1%; ManufacturerPN TLRP2B10DR030FTD
R30, R70: RES_DNP_1206; R_1206_3216Metric; ManufacturerPN DNP; not fitted
R31: RES_499K_1P_1/4W_1206; R_1206_3216Metric; Tolerance ±1%; ManufacturerPN RC1206FR-07499KL
R33: RES_2K8_1P_1/10W_0603; R_0603_1608Metric; Tolerance ±1%; ManufacturerPN RC0603FR-072K8L
R43: RES_33K_1P_1/10W_0603; R_0603_1608Metric; Tolerance ±1%; ManufacturerPN RMCF0603FT33K0
R44, R46: RES_4K7_1P_1/10W_0603; R_0603_1608Metric; Tolerance ±1%; ManufacturerPN RC0603FR-074K7L
R45: RES_499K_1P_1/4W_0805; R_1206_3216Metric; Tolerance ±1%; ManufacturerPN RC1206FR-07499KL
R67: RES_1K5_1P_1/10W_0603; R_0603_1608Metric; Tolerance ±1%; ManufacturerPN RC0603FR-071K5L
R68: RES_9K31_1P_1/10W_0603; R_0603_1608Metric; Tolerance ±1%; ManufacturerPN RC0603FR-079K31L
R69: RES_698R_1P_1/10W_0603; R_0603_1608Metric; Tolerance ±1%; ManufacturerPN RC0603FR-07698RL
TP2: 12V; TestPoint_Keystone_5019_Minature; ManufacturerPN 5019
TP3: 3V3; TestPoint_Keystone_5019_Minature; ManufacturerPN 5019
TP4: 180V; TestPoint_Keystone_5019_Minature; ManufacturerPN 5019
U5: REG_SW_BOOST_TI_TLV61046ADBV; SOT-23-6_TI; ManufacturerPN TLV61046ADBVR
U6: REG_SW_BOOST_TI_LM51561HPWPR; PWP0014H-MFG; ManufacturerPN LM51561HPWPR
U7: REG_LDO_3V3_250mA_TI_LP5907MFX-3.3; SOT-23-5_TI; ManufacturerPN LP5907MFX-3.3/NOPB

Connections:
180V: C44.1, C45.1, C46.1, C65.1, D1.1 (K), R30.1, R31.1, R45.1, TP4.1; also elsewhere on the board
+3.3V: C41.1, C42.1, R20.1, R69.1, TP3.1, U7.5 (OUT); also elsewhere on the board
+5V: FB2.1, FB3.1, FB4.1; also elsewhere on the board
+12V: C28.1, C29.1, C30.1, C31.1, C33.1, R21.1, R43.1, R68.1, TP2.1, U5.5 (VOUT), U6.1 (BIAS), U6.3 (VCC); also elsewhere on the board
/MCU/DITHOFF_180V: R23.1, U6.9 (DITHOFF); also elsewhere on the board
/MCU/EN_12V: R17.1, U5.4 (EN); also elsewhere on the board
/MCU/EN_180V: R19.1, R67.1, U6.14 (EN_UVLO_SYNC); also elsewhere on the board
/MCU/PG_180V: R20.2, U6.13 (PGOOD); also elsewhere on the board
/MCU/SENSE_12V: C54.1, R43.2, R44.1; also elsewhere on the board
/MCU/SENSE_180V: C55.1, R45.2, R46.1; also elsewhere on the board
/Power/COMP_180V: C36.1, R27.1, U6.8 (COMP)
/Power/COMP_180V_RC: C34.1, R27.2
/Power/CS_FILT: C35.1, R26.1, R28.2
/Power/CS_FILT_R: R26.2, U6.7 (CS)
/Power/CS_RAW: Q1.S, R28.1, R29.1
/Power/D_SNUB: C39.2, R30.2
/Power/FB_12V: R18.1, R21.2, R22.1, U5.3 (FB)
/Power/FB_180V: R31.2, R33.1, U6.10 (FB)
/Power/GATE: Q1.G, R25.1
/Power/GATE_R: R25.2, U6.4 (GATE)
/Power/Q_SNUB: C40.2, R70.1
/Power/RT_180V: R24.1, U6.12 (RT)
/Power/SS_180V: C32.1, U6.11 (SS)
/Power/SW_12V: L1.2, U5.1 (SW)
/Power/SW_180V: C39.1, C40.1, D1.2 (A), L2.2, Q1.D
/Power/VIN_3V3: C37.1, C38.1, FB4.2, U7.1 (IN), U7.3 (EN)
/Power/VIN_12V: C21.1, C22.1, FB2.2, L1.1, R18.2, U5.6 (VIN)
/Power/VIN_180V: C23.1, C24.1, C25.1, C26.1, C27.1, FB3.2, L2.1
GND: C21.2, C22.2, C23.2, C24.2, C25.2, C26.2, C27.2, C28.2, C29.2, C30.2, C31.2, C32.2, C33.2, C34.2, C35.2, C36.2, C37.2, C38.2, C41.2, C42.2, C44.2, C45.2, C46.2, C54.2, C55.2, C65.2, D8.1 (K), D9.1 (K), D10.1 (K), R17.2, R19.2, R22.2, R23.2, R24.2, R29.2, R33.2, R44.2, R46.2, R70.2, U5.2 (GND), U6.5 (PGND), U6.6 (AGND), U6.15 (EP), U7.2 (GND); also elsewhere on the board
unnamed: D8.2 (A), R67.2
unnamed: D9.2 (A), R68.2
unnamed: D10.2 (A), R69.2

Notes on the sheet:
!! Check level shifter power sequencing requirements
FB to VIN defaults to 12V out Pout_max = 384mW Vout_ripple = 30mV (PFM), 2.6mV (PWM) Iout_max = 32mA In_max = 93mA
9.33 mV/V 180V input -> 1.6795V at ADC input 3.3V at ADC input would need to be a 353V input.. Input impedance to ADC is 499k||4.7k = 4.67k - This is less than 50k max R_ain of the ADC fc = 342Hz - Place filter cap near MCU pin
1mA
124.7 mV/V 12V input -> 1.496V at ADC input 3.3V at ADC input would need to be a 26.5V input Input impedance to ADC is 33k||4.7k = 4.11k - This is less than 50k max R_ain of the ADC fc = 387 Hz - Place filter cap near MCU pin
Cout: -24% derating at 12V 4.7uF * 2 * 0.76 = 7.14uF
R27 and C36 add a low frequency compensation zero at 1.5kHz C34 adds a high frequency compensation pole at 327kHz
100uF cap derated to ~46uF at 5V -> 138uF at input for approx 100mV ripple
Add PG Pull up at MCU pin
1uF cap derated to ~.3uF at 180V -> 1uF at output
RT = 61.9k -> Fs = 351.6kHz SS = 0.uF -> 9.7ms Startup 100mV input and output ripple
Pout_max = 81.1mW Iout_max = 24.8mA Ploss = 42.2mW
Cin: -2.5% derating at 5V 1uF * 0.975 = 0.975uF

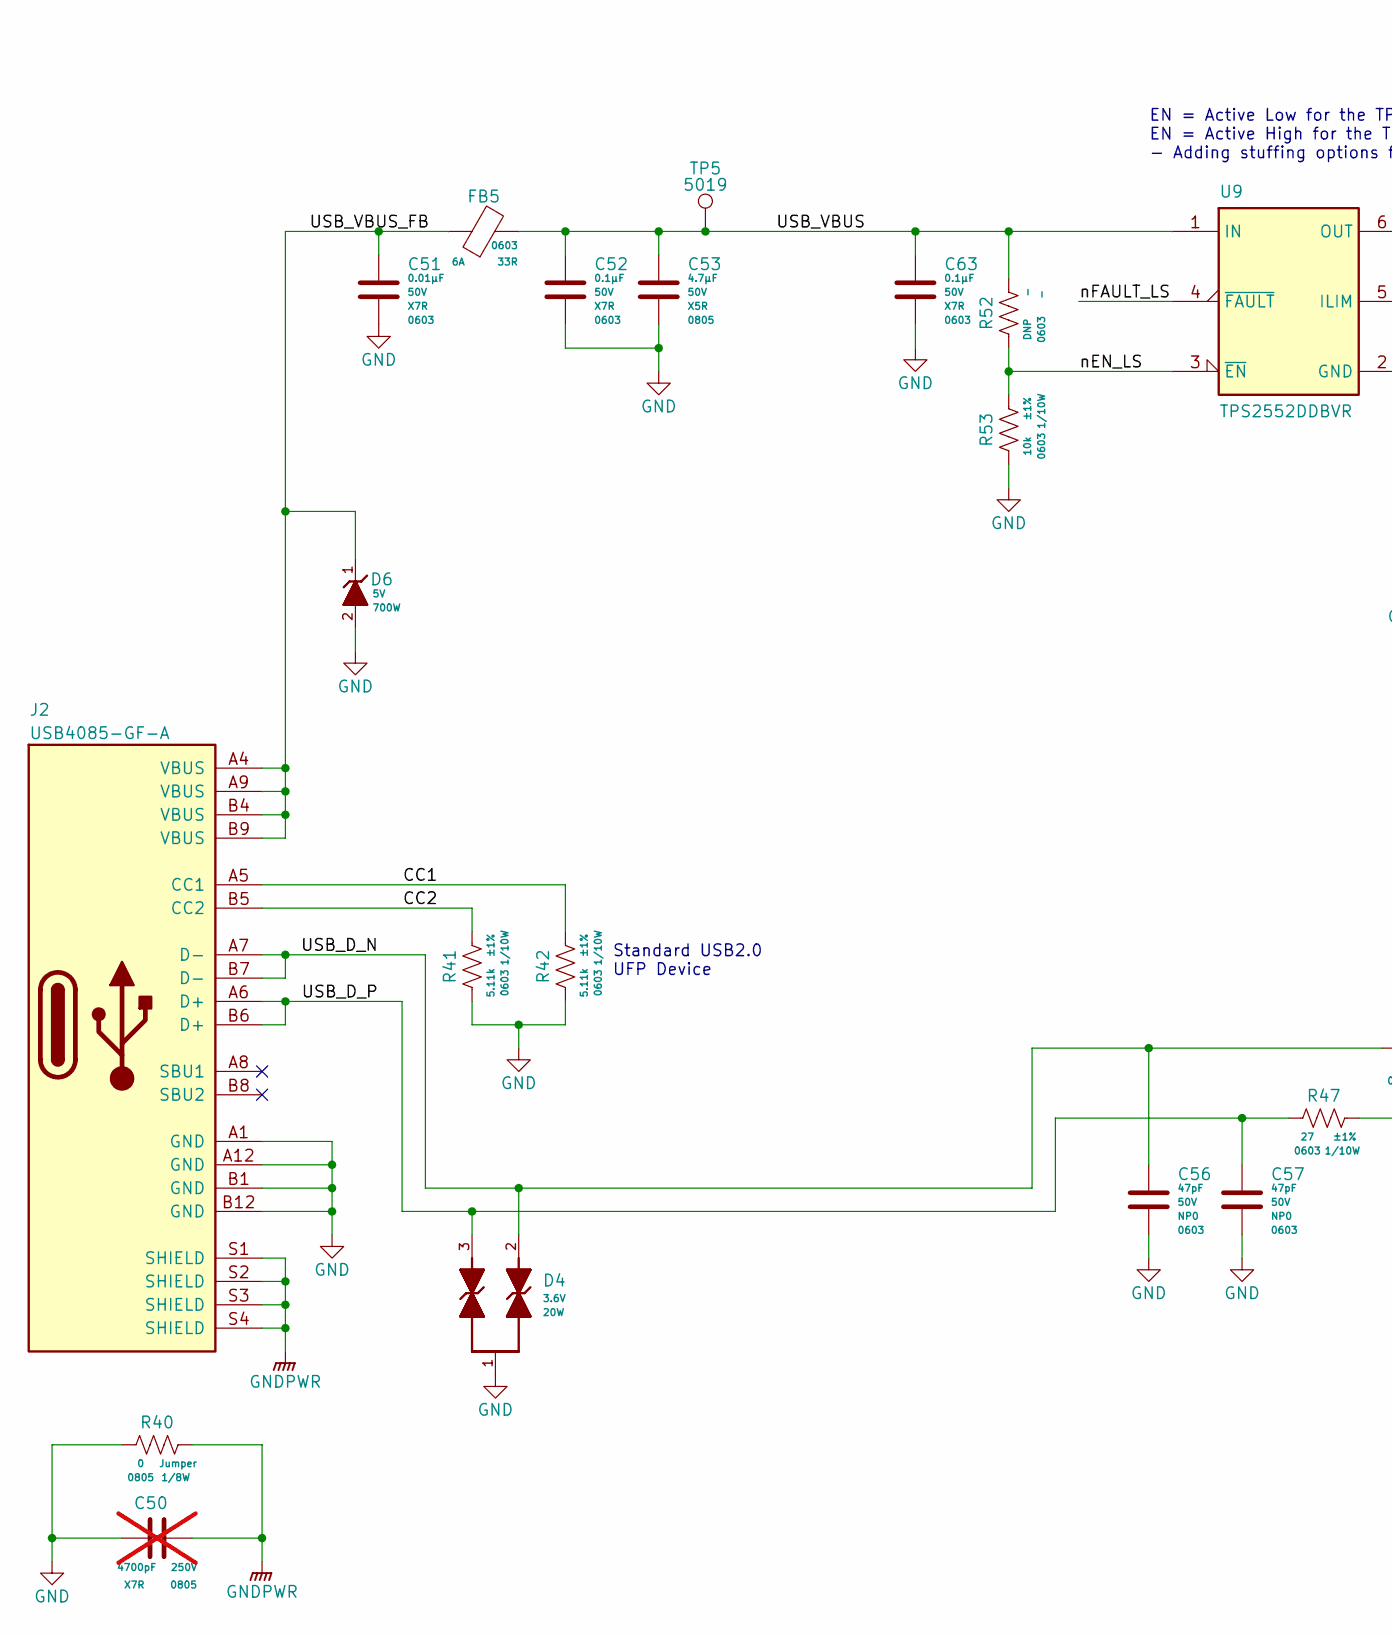
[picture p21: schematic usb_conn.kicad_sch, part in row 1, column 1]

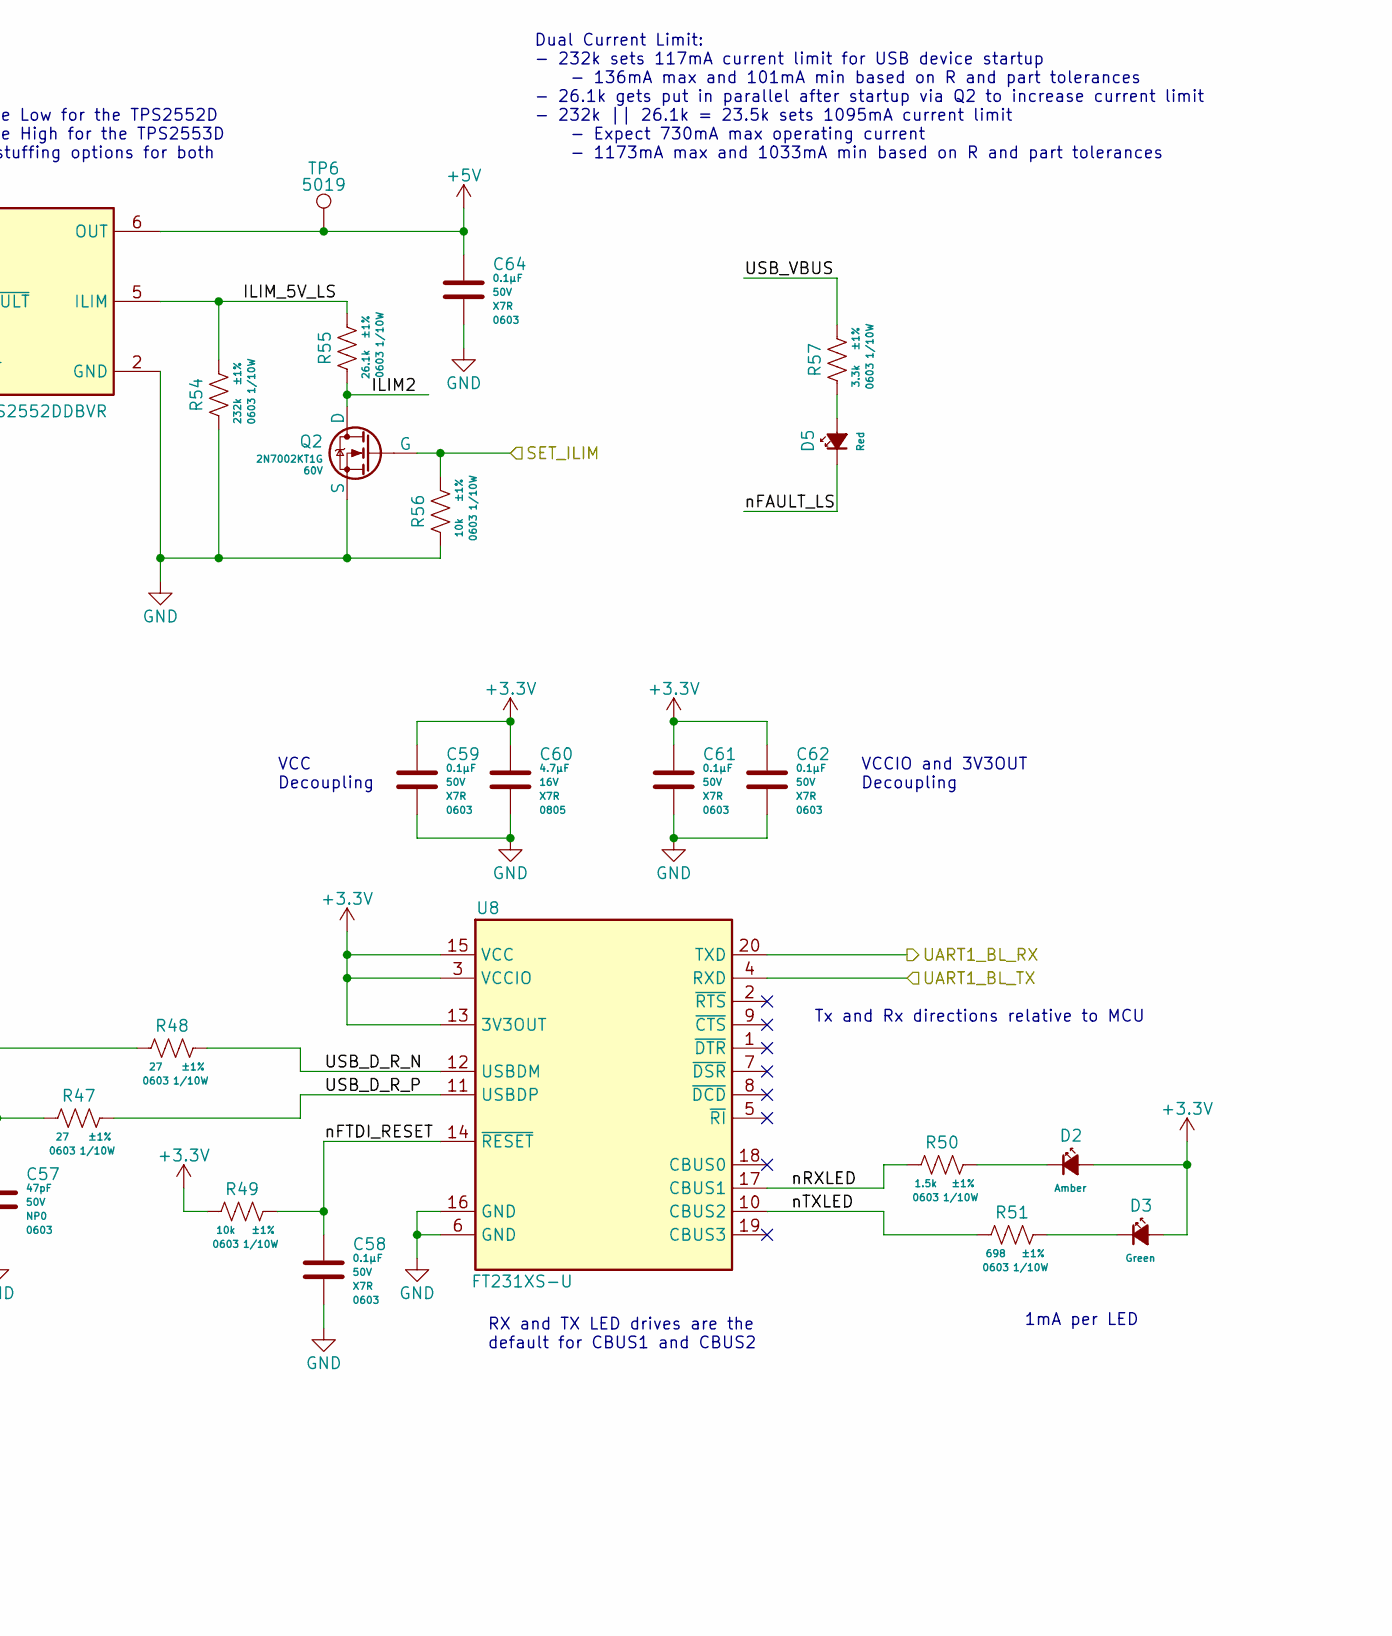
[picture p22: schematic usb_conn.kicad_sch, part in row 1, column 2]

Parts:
C50: CAP_CER_4700p_250V_X7R_0805; C_0805_2012Metric; Voltage 250V; ManufacturerPN CC0805KRX7RYBB472; not fitted
C51: CAP_CER_0u01_50V_X7R_0603; C_0603_1608Metric; Voltage 50V; ManufacturerPN CL10B103KB8NNNC
C52, C58, C59, C61, C62, C63, C64: CAP_CER_0u1_50V_X7R_0603; C_0603_1608Metric; Voltage 50V; ManufacturerPN CL10B104KB8NNNC
C53: CAP_CER_4u7_50V_X5R_0805; C_0805_2012Metric; Voltage 50V; ManufacturerPN GRM21BR61H475KE51L
C56, C57: CAP_CER_47p_50V_NP0_0603; C_0603_1608Metric; Voltage 50V; ManufacturerPN CL10C470JB8NNNC
C60: CAP_CER_4u7_16V_X7R_0805; C_0805_2012Metric; Voltage 16V; ManufacturerPN GRM21BR71C475KE51L
D2: LED_AMBER_0603; LED_0603_1608Metric; ManufacturerPN 150060AS75000
D3: LED_GREEN_0603; LED_0603_1608Metric; ManufacturerPN 150060GS75000
D4: D_TVS_BI_3V6_20W_3-XFDFN; DIO_ESD122DMYR; ManufacturerPN ESD122DMYR
D5: LED_RED_0603; LED_0603_1608Metric; ManufacturerPN 150060RS75000
D6: D_TVS_UNI_5V_700W_2-UDFN; QFN-2L_STM; ManufacturerPN ESDA7P60-1U1M
FB5: FER_33R_6A_0603; L_0603_1608Metric; ManufacturerPN BLM18SG330SN1D
J2: CONN_USBC_RCPT_USB2.0_USB4085-GF-A; GCT_USB4085-GF-A_REVA4; ManufacturerPN USB4085-GF-A
Q2: NFET_60V_0A5_2N7002KT1G; SOT-23_ONSEMI; ManufacturerPN 2N7002KT1G
R40: RES_0R_1/8W_0805; R_0805_2012Metric; Tolerance Jumper; ManufacturerPN RMCF0805ZT0R00
R41, R42: RES_5K11_1P_1/10W_0603; R_0603_1608Metric; Tolerance ±1%; ManufacturerPN CRCW06035K11FKEAC
R47, R48: RES_27R_1P_1/10W_0603; R_0603_1608Metric; Tolerance ±1%; ManufacturerPN RC0603JR-0727RL
R49, R53, R56: RES_10K_1P_1/10W_0603; R_0603_1608Metric; Tolerance ±1%; ManufacturerPN RC0603FR-0710KL
R50: RES_1K5_1P_1/10W_0603; R_0603_1608Metric; Tolerance ±1%; ManufacturerPN RC0603FR-071K5L
R51: RES_698R_1P_1/10W_0603; R_0603_1608Metric; Tolerance ±1%; ManufacturerPN RC0603FR-07698RL
R52: RES_DNP_0603; R_0603_1608Metric; ManufacturerPN DNP
R54: RES_232K_1P_1/10W_0603; R_0603_1608Metric; Tolerance ±1%; ManufacturerPN RC0603FR-07232KL
R55: RES_26K1_1P_1/10W_0603; R_0603_1608Metric; Tolerance ±1%; ManufacturerPN RC0603FR-0726K1L
R57: RES_3K3_1P_1/10W_0603; R_0603_1608Metric; Tolerance ±1%; ManufacturerPN RMCF0603FT3K30
TP5: VBUS; TestPoint_Keystone_5019_Minature; ManufacturerPN 5019
TP6: 5V; TestPoint_Keystone_5019_Minature; ManufacturerPN 5019
U8: IC_FTDI_FT231XS; SSOP-20_3.9x8.7mm_P0.635mm; ManufacturerPN FT231XS-U
U9: IC_LSW_TI_TPS2552D; SOT-23-6_TI; ManufacturerPN TPS2552DDBVR

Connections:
+3.3V: C59.1, C60.1, C61.1, C62.1, D2.2 (A), D3.2 (A), R49.2, U8.3 (VCCIO), U8.13 (3V3OUT), U8.15 (VCC); also elsewhere on the board
+5V: C64.1, TP6.1, U9.6 (OUT); also elsewhere on the board
/MCU/SET_ILIM: Q2.1 (G), R56.1; also elsewhere on the board
/MCU/UART1_BL_RX: U8.20 (TXD); also elsewhere on the board
/MCU/UART1_BL_TX: U8.4 (RXD); also elsewhere on the board
/USB Connector/CC1: J2.A5 (CC1), R42.1
/USB Connector/CC2: J2.B5 (CC2), R41.1
/USB Connector/ILIM2: Q2.3 (D), R55.2
/USB Connector/ILIM_5V_LS: R54.1, R55.1, U9.5 (ILIM)
/USB Connector/USB_D_N: C56.1, D4.2, J2.A7 (D-), J2.B7 (D-), R48.2
/USB Connector/USB_D_P: C57.1, D4.3, J2.A6 (D+), J2.B6 (D+), R47.2
/USB Connector/USB_D_R_N: R48.1, U8.12 (USBDM)
/USB Connector/USB_D_R_P: R47.1, U8.11 (USBDP)
/USB Connector/USB_VBUS: C52.1, C53.1, C63.1, FB5.2, R52.1, R57.1, TP5.1, U9.1 (IN)
/USB Connector/USB_VBUS_FB: C51.1, D6.1 (K), FB5.1, J2.A4 (VBUS), J2.A9 (VBUS), J2.B4 (VBUS), J2.B9 (VBUS)
/USB Connector/nEN_LS: R52.2, R53.1, U9.3 (~EN)
/USB Connector/nFAULT_LS: D5.1 (K), U9.4 (~FAULT)
/USB Connector/nFTDI_RESET: C58.1, R49.1, U8.14 (~RESET)
/USB Connector/nRXLED: R50.2, U8.17 (CBUS1)
/USB Connector/nTXLED: R51.2, U8.10 (CBUS2)
GND: C50.1, C51.2, C52.2, C53.2, C56.2, C57.2, C58.2, C59.2, C60.2, C61.2, C62.2, C63.2, C64.2, D4.1, D6.2 (A), J2.A1 (GND), J2.A12 (GND), J2.B1 (GND), J2.B12 (GND), Q2.2 (S), R40.2, R41.2, R42.2, R53.2, R54.2, R56.2, U8.6 (GND), U8.16 (GND), U9.2 (GND); also elsewhere on the board
GNDPWR: C50.2, J2.S1 (SHIELD), J2.S2 (SHIELD), J2.S3 (SHIELD), J2.S4 (SHIELD), R40.1
unnamed: D2.1 (K), R50.1
unnamed: D3.1 (K), R51.1
unnamed: D5.2 (A), R57.2

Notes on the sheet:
VCC Decoupling
RX and TX LED drives are the default for CBUS1 and CBUS2
EN = Active Low for the TPS2552D EN = Active High for the TPS2553D - Adding stuffing options for both
Standard USB2.0 UFP Device
Dual Current Limit: - 232k sets 117mA current limit for USB device startup - 136mA max and 101mA min based on R and part tolerances - 26.1k gets put in parallel after startup via Q2 to increase current limit - 232k || 26.1k = 23.5k sets 1095mA current limit - Expect 730mA max operating current - 11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
VCCIO and 3V3OUT Decoupling
Tx and Rx directions relative to MCU
1mA per LED

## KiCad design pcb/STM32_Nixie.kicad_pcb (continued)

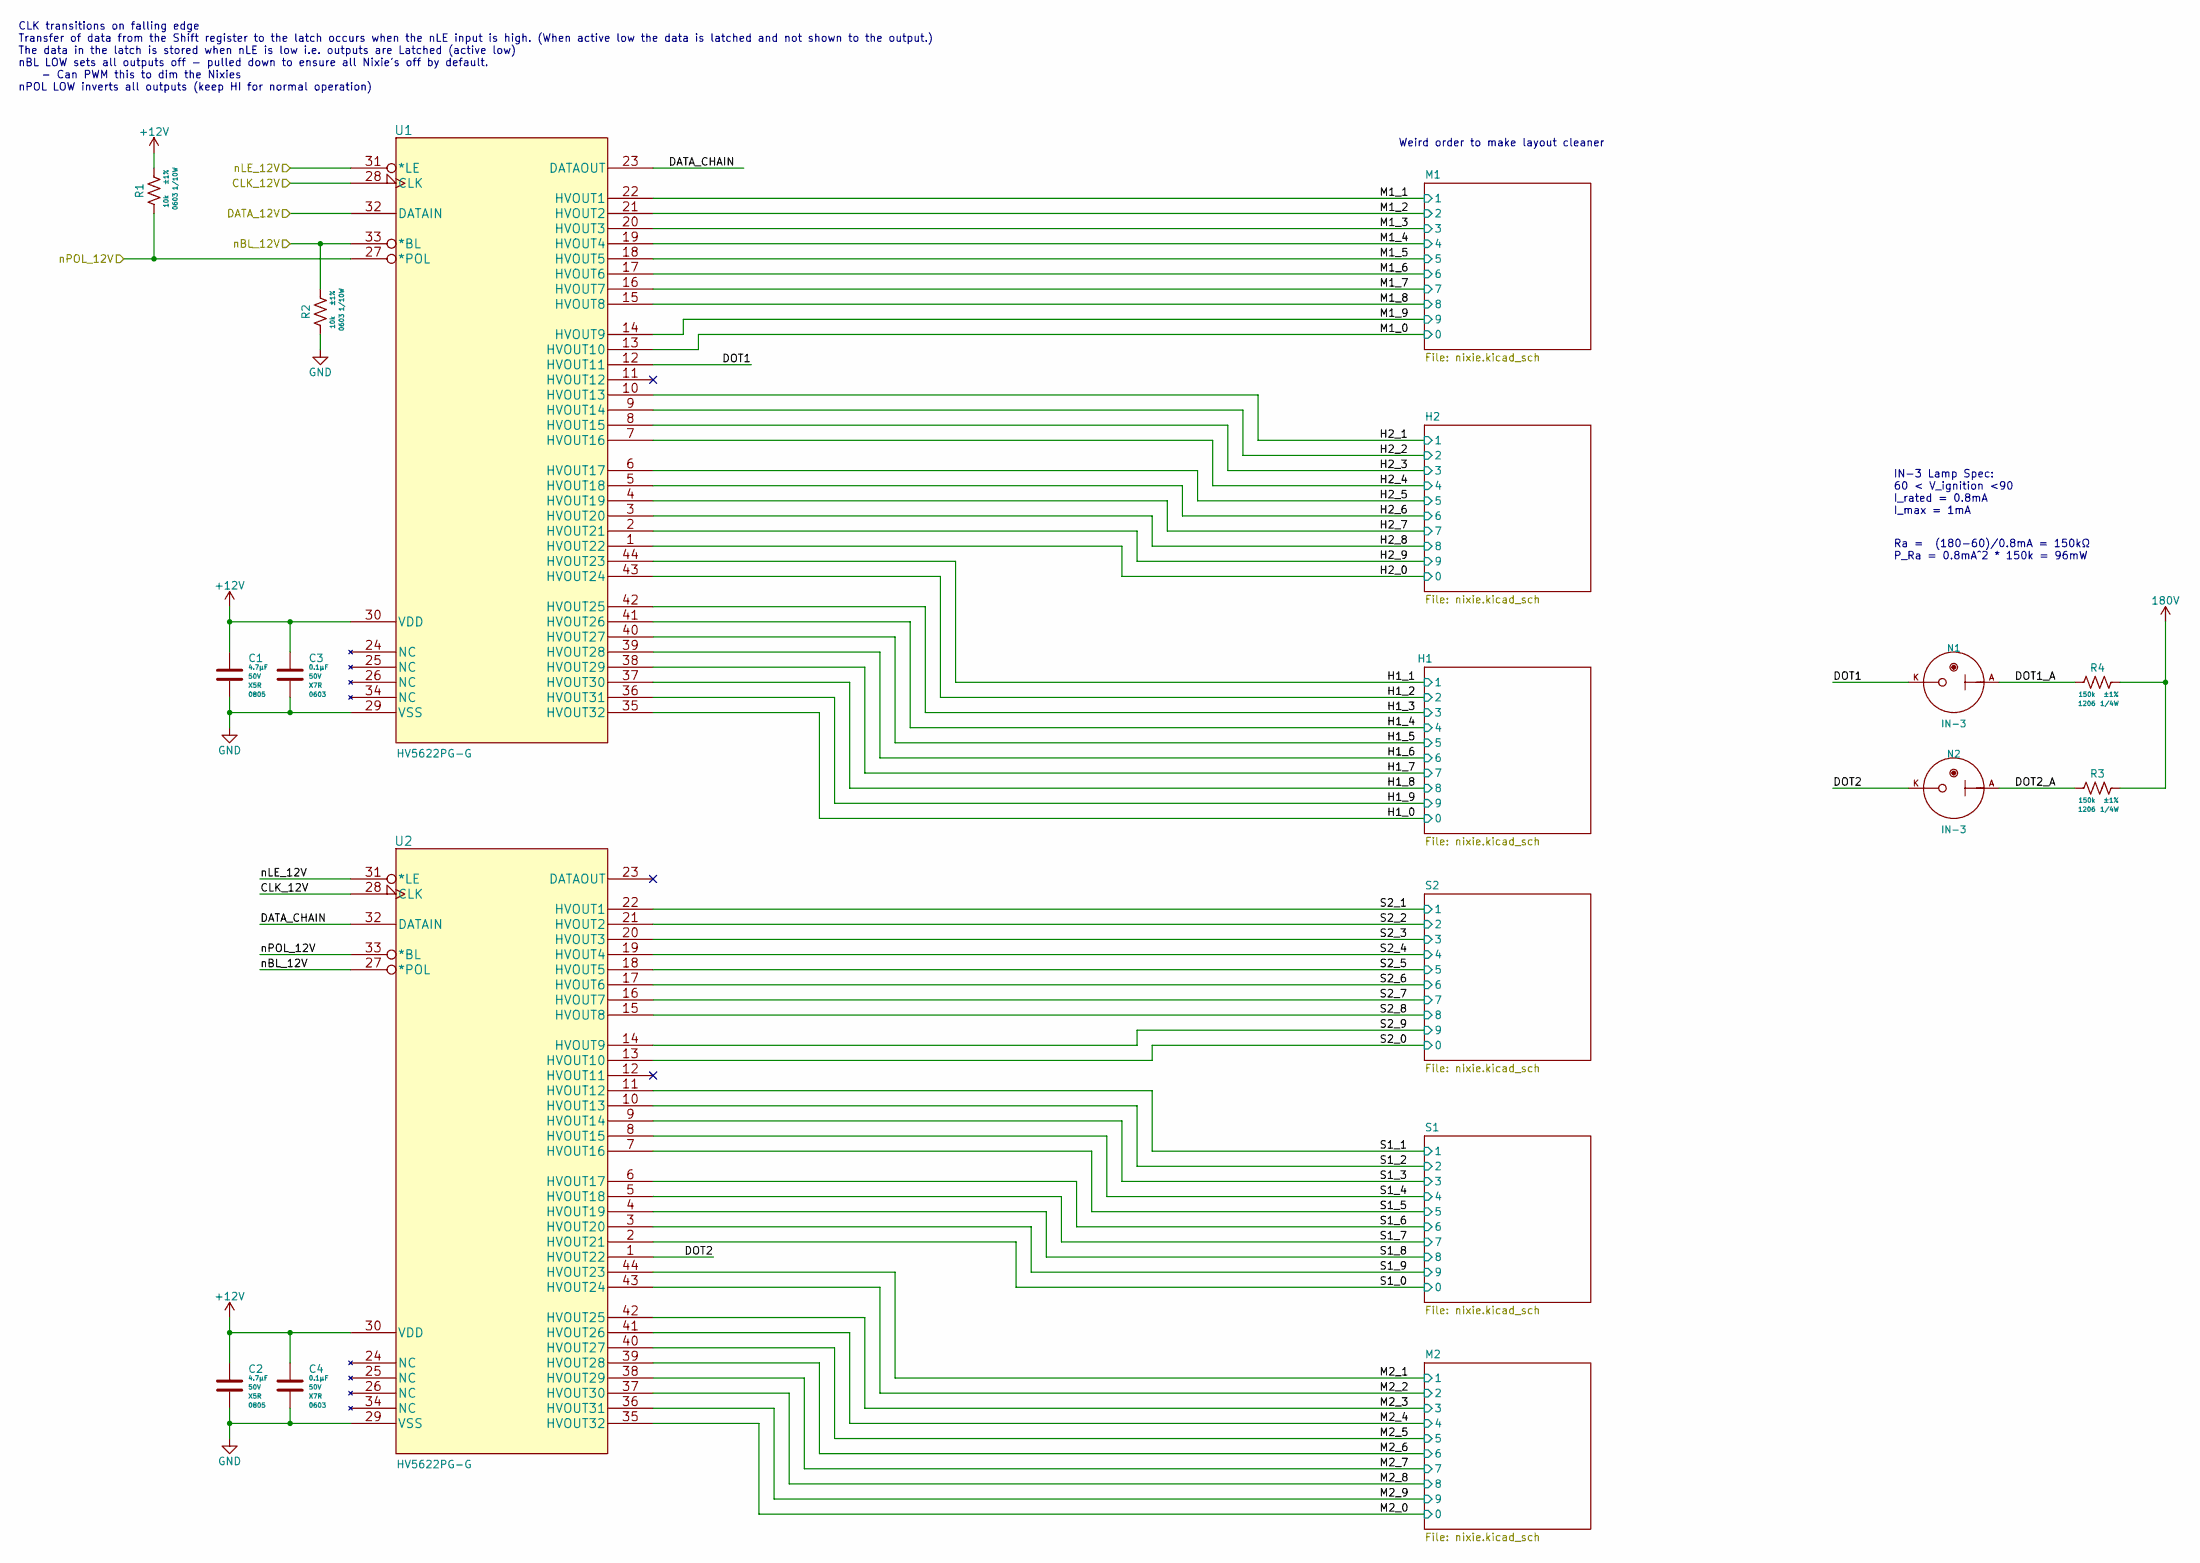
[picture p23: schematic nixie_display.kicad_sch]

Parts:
C1, C2: CAP_CER_4u7_50V_X5R_0805; C_0805_2012Metric; Voltage 50V; ManufacturerPN GRM21BR61H475KE51L
C3, C4: CAP_CER_0u1_50V_X7R_0603; C_0603_1608Metric; Voltage 50V; ManufacturerPN CL10B104KB8NNNC
N1, N2: IN-3
R1, R2: RES_10K_1P_1/10W_0603; R_0603_1608Metric; Tolerance ±1%; ManufacturerPN RC0603FR-0710KL
R3, R4: RES_150K_1P_1/4W_1206; R_1206_3216Metric; Tolerance ±1%; ManufacturerPN RC1206FR-07150KL
U1, U2: IC_SR_MC_HV5622PG-G; HV5622PG-G; ManufacturerPN HV5622PG-G

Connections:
180V: R3.1, R4.1; also elsewhere on the board
+12V: C1.1, C2.1, C3.1, C4.1, R1.1, U1.30 (VDD), U2.30 (VDD); also elsewhere on the board
/Nixie Display/DATA_CHAIN: U1.23 (DATAOUT), U2.32 (DATAIN)
/Nixie Display/DOT1: N1.K, U1.12 (HVOUT11)
/Nixie Display/DOT1_A: N1.A, R4.2
/Nixie Display/DOT2: N2.K, U2.1 (HVOUT22)
/Nixie Display/DOT2_A: N2.A, R3.2
/Nixie Display/H1_0: U1.35 (HVOUT32); also elsewhere on the board
/Nixie Display/H1_1: U1.44 (HVOUT23); also elsewhere on the board
/Nixie Display/H1_2: U1.43 (HVOUT24); also elsewhere on the board
/Nixie Display/H1_3: U1.42 (HVOUT25); also elsewhere on the board
/Nixie Display/H1_4: U1.41 (HVOUT26); also elsewhere on the board
/Nixie Display/H1_5: U1.40 (HVOUT27); also elsewhere on the board
/Nixie Display/H1_6: U1.39 (HVOUT28); also elsewhere on the board
/Nixie Display/H1_7: U1.38 (HVOUT29); also elsewhere on the board
/Nixie Display/H1_8: U1.37 (HVOUT30); also elsewhere on the board
/Nixie Display/H1_9: U1.36 (HVOUT31); also elsewhere on the board
/Nixie Display/H2_0: U1.1 (HVOUT22); also elsewhere on the board
/Nixie Display/H2_1: U1.10 (HVOUT13); also elsewhere on the board
/Nixie Display/H2_2: U1.9 (HVOUT14); also elsewhere on the board
/Nixie Display/H2_3: U1.8 (HVOUT15); also elsewhere on the board
/Nixie Display/H2_4: U1.7 (HVOUT16); also elsewhere on the board
/Nixie Display/H2_5: U1.6 (HVOUT17); also elsewhere on the board
/Nixie Display/H2_6: U1.5 (HVOUT18); also elsewhere on the board
/Nixie Display/H2_7: U1.4 (HVOUT19); also elsewhere on the board
/Nixie Display/H2_8: U1.3 (HVOUT20); also elsewhere on the board
/Nixie Display/H2_9: U1.2 (HVOUT21); also elsewhere on the board
/Nixie Display/M1_0: U1.13 (HVOUT10); also elsewhere on the board
/Nixie Display/M1_1: U1.22 (HVOUT1); also elsewhere on the board
/Nixie Display/M1_2: U1.21 (HVOUT2); also elsewhere on the board
/Nixie Display/M1_3: U1.20 (HVOUT3); also elsewhere on the board
/Nixie Display/M1_4: U1.19 (HVOUT4); also elsewhere on the board
/Nixie Display/M1_5: U1.18 (HVOUT5); also elsewhere on the board
/Nixie Display/M1_6: U1.17 (HVOUT6); also elsewhere on the board
/Nixie Display/M1_7: U1.16 (HVOUT7); also elsewhere on the board
/Nixie Display/M1_8: U1.15 (HVOUT8); also elsewhere on the board
/Nixie Display/M1_9: U1.14 (HVOUT9); also elsewhere on the board
/Nixie Display/M2_0: U2.35 (HVOUT32); also elsewhere on the board
/Nixie Display/M2_1: U2.44 (HVOUT23); also elsewhere on the board
/Nixie Display/M2_2: U2.43 (HVOUT24); also elsewhere on the board
/Nixie Display/M2_3: U2.42 (HVOUT25); also elsewhere on the board
/Nixie Display/M2_4: U2.41 (HVOUT26); also elsewhere on the board
/Nixie Display/M2_5: U2.40 (HVOUT27); also elsewhere on the board
/Nixie Display/M2_6: U2.39 (HVOUT28); also elsewhere on the board
/Nixie Display/M2_7: U2.38 (HVOUT29); also elsewhere on the board
/Nixie Display/M2_8: U2.37 (HVOUT30); also elsewhere on the board
/Nixie Display/M2_9: U2.36 (HVOUT31); also elsewhere on the board
/Nixie Display/S1_0: U2.2 (HVOUT21); also elsewhere on the board
/Nixie Display/S1_1: U2.11 (HVOUT12); also elsewhere on the board
/Nixie Display/S1_2: U2.10 (HVOUT13); also elsewhere on the board
/Nixie Display/S1_3: U2.9 (HVOUT14); also elsewhere on the board
/Nixie Display/S1_4: U2.8 (HVOUT15); also elsewhere on the board
/Nixie Display/S1_5: U2.7 (HVOUT16); also elsewhere on the board
/Nixie Display/S1_6: U2.6 (HVOUT17); also elsewhere on the board
/Nixie Display/S1_7: U2.5 (HVOUT18); also elsewhere on the board
/Nixie Display/S1_8: U2.4 (HVOUT19); also elsewhere on the board
/Nixie Display/S1_9: U2.3 (HVOUT20); also elsewhere on the board
/Nixie Display/S2_0: U2.13 (HVOUT10); also elsewhere on the board
/Nixie Display/S2_1: U2.22 (HVOUT1); also elsewhere on the board
/Nixie Display/S2_2: U2.21 (HVOUT2); also elsewhere on the board
/Nixie Display/S2_3: U2.20 (HVOUT3); also elsewhere on the board
/Nixie Display/S2_4: U2.19 (HVOUT4); also elsewhere on the board
/Nixie Display/S2_5: U2.18 (HVOUT5); also elsewhere on the board
/Nixie Display/S2_6: U2.17 (HVOUT6); also elsewhere on the board
/Nixie Display/S2_7: U2.16 (HVOUT7); also elsewhere on the board
/Nixie Display/S2_8: U2.15 (HVOUT8); also elsewhere on the board
/Nixie Display/S2_9: U2.14 (HVOUT9); also elsewhere on the board
/PWM_nBL_12V: R2.1, U1.33 (*BL), U2.27 (*POL); also elsewhere on the board
/SPI_PICO_12V: U1.32 (DATAIN); also elsewhere on the board
/SPI_SCK_12V: U1.28 (CLK), U2.28 (CLK); also elsewhere on the board
/SPI_nCS_nLE_12V: U1.31 (*LE), U2.31 (*LE); also elsewhere on the board
/nPOL_12V: R1.2, U1.27 (*POL), U2.33 (*BL); also elsewhere on the board
GND: C1.2, C2.2, C3.2, C4.2, R2.2, U1.29 (VSS), U2.29 (VSS); also elsewhere on the board

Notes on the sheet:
CLK transitions on falling edge Transfer of data from the Shift register to the latch occurs when the nLE input is high. (When active low the data is latched and not shown to the output.) The data in the latch is stored when nLE is low i.e. outputs are Latched (active low) nBL LOW sets all outputs 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
Ra = (180-60)/0.8mA = 150kΩ P_Ra = 0.8mA^2 * 150k = 96mW
Weird order to make layout cleaner
IN-3 Lamp Spec: 60 < V_ignition <90 I_rated = 0.8mA I_max = 1mA

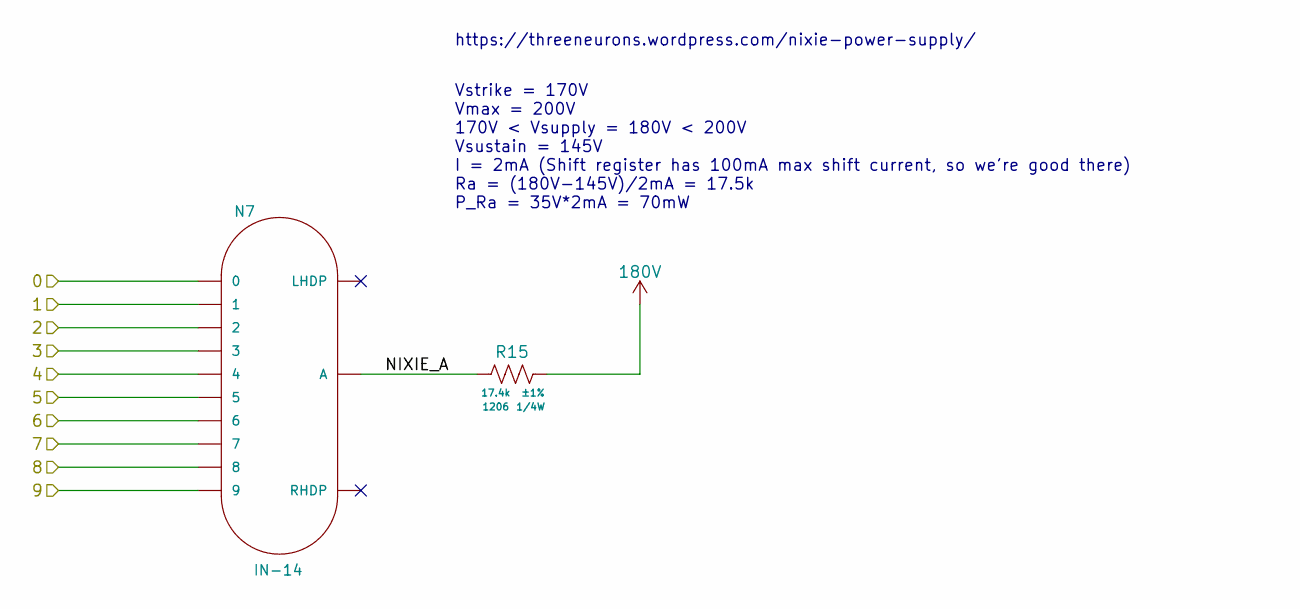
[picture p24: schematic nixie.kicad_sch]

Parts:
N7: IN-14
R15: RES_17K4_1P_1/4W_1206; R_1206_3216Metric; Tolerance ±1%; ManufacturerPN RC1206FR-0717K4L

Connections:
180V: R15.1; also elsewhere on the board
/Nixie Display/S1/NIXIE_A: N7.A, R15.2
/Nixie Display/S1_0: N7.0; also elsewhere on the board
/Nixie Display/S1_1: N7.1; also elsewhere on the board
/Nixie Display/S1_2: N7.2; also elsewhere on the board
/Nixie Display/S1_3: N7.3; also elsewhere on the board
/Nixie Display/S1_4: N7.4; also elsewhere on the board
/Nixie Display/S1_5: N7.5; also elsewhere on the board
/Nixie Display/S1_6: N7.6; also elsewhere on the board
/Nixie Display/S1_7: N7.7; also elsewhere on the board
/Nixie Display/S1_8: N7.8; also elsewhere on the board
/Nixie Display/S1_9: N7.9; also elsewhere on the board

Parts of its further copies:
N3, N4, N5, N6, N8: IN-14
R11, R12, R13, R14, R16: RES_17K4_1P_1/4W_1206; R_1206_3216Metric; Tolerance ±1%; ManufacturerPN RC1206FR-0717K4L

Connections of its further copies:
180V: R11.1, R12.1, R13.1, R14.1, R16.1; also elsewhere on the board
/Nixie Display/H1/NIXIE_A: N3.A, R11.2
/Nixie Display/H1_0: N3.0; also elsewhere on the board
/Nixie Display/H1_1: N3.1; also elsewhere on the board
/Nixie Display/H1_2: N3.2; also elsewhere on the board
/Nixie Display/H1_3: N3.3; also elsewhere on the board
/Nixie Display/H1_4: N3.4; also elsewhere on the board
/Nixie Display/H1_5: N3.5; also elsewhere on the board
/Nixie Display/H1_6: N3.6; also elsewhere on the board
/Nixie Display/H1_7: N3.7; also elsewhere on the board
/Nixie Display/H1_8: N3.8; also elsewhere on the board
/Nixie Display/H1_9: N3.9; also elsewhere on the board
/Nixie Display/H2/NIXIE_A: N4.A, R12.2
/Nixie Display/H2_0: N4.0; also elsewhere on the board
/Nixie Display/H2_1: N4.1; also elsewhere on the board
/Nixie Display/H2_2: N4.2; also elsewhere on the board
/Nixie Display/H2_3: N4.3; also elsewhere on the board
/Nixie Display/H2_4: N4.4; also elsewhere on the board
/Nixie Display/H2_5: N4.5; also elsewhere on the board
/Nixie Display/H2_6: N4.6; also elsewhere on the board
/Nixie Display/H2_7: N4.7; also elsewhere on the board
/Nixie Display/H2_8: N4.8; also elsewhere on the board
/Nixie Display/H2_9: N4.9; also elsewhere on the board
/Nixie Display/M1/NIXIE_A: N5.A, R13.2
/Nixie Display/M1_0: N5.0; also elsewhere on the board
/Nixie Display/M1_1: N5.1; also elsewhere on the board
/Nixie Display/M1_2: N5.2; also elsewhere on the board
/Nixie Display/M1_3: N5.3; also elsewhere on the board
/Nixie Display/M1_4: N5.4; also elsewhere on the board
/Nixie Display/M1_5: N5.5; also elsewhere on the board
/Nixie Display/M1_6: N5.6; also elsewhere on the board
/Nixie Display/M1_7: N5.7; also elsewhere on the board
/Nixie Display/M1_8: N5.8; also elsewhere on the board
/Nixie Display/M1_9: N5.9; also elsewhere on the board
/Nixie Display/M2/NIXIE_A: N6.A, R14.2
/Nixie Display/M2_0: N6.0; also elsewhere on the board
/Nixie Display/M2_1: N6.1; also elsewhere on the board
/Nixie Display/M2_2: N6.2; also elsewhere on the board
/Nixie Display/M2_3: N6.3; also elsewhere on the board
/Nixie Display/M2_4: N6.4; also elsewhere on the board
/Nixie Display/M2_5: N6.5; also elsewhere on the board
/Nixie Display/M2_6: N6.6; also elsewhere on the board
/Nixie Display/M2_7: N6.7; also elsewhere on the board
/Nixie Display/M2_8: N6.8; also elsewhere on the board
/Nixie Display/M2_9: N6.9; also elsewhere on the board
/Nixie Display/S2/NIXIE_A: N8.A, R16.2
/Nixie Display/S2_0: N8.0; also elsewhere on the board
/Nixie Display/S2_1: N8.1; also elsewhere on the board
/Nixie Display/S2_2: N8.2; also elsewhere on the board
/Nixie Display/S2_3: N8.3; also elsewhere on the board
/Nixie Display/S2_4: N8.4; also elsewhere on the board
/Nixie Display/S2_5: N8.5; also elsewhere on the board
/Nixie Display/S2_6: N8.6; also elsewhere on the board
/Nixie Display/S2_7: N8.7; also elsewhere on the board
/Nixie Display/S2_8: N8.8; also elsewhere on the board
/Nixie Display/S2_9: N8.9; also elsewhere on the board

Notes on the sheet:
Vstrike = 170V Vmax = 200V 170V < Vsupply = 180V < 200V Vsustain = 145V I = 2mA (Shift register has 100mA max shift current, so we're good there) Ra = (180V-145V)/2mA = 17.5k P_Ra = 35V*2mA = 70mW
https://threeneurons.wordpress.com/nixie-power-supply/


Board: 4 copper layers, 154.0 x 57.0 mm, 185 parts (1 on the bottom side), 172 nets.

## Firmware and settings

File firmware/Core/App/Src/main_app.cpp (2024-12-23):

// main_app.cpp

#include "main_app.hh"

#include <array>

#include "debug.hh"
#include "hv5622_driver.hh"
#include "main.h"
#include "menu.hh"
#include "nixie_display.hh"
#include "system_control.hh"
#include "time_lord.hh"
#include "user_input.hh"

// Using the separate main_app because CubeMX code generation will keep making a
// new main.c and clobbers the main.cpp. Instead this main_app gets called in
// main.c so CubeMX can happily keep generating code.

// These tell the C++ compiler that these symbols come from C code
extern "C" {
extern SPI_HandleTypeDef hspi1;    // Defined in spi.c
extern ADC_HandleTypeDef hadc1;    // Defined in adc.c
extern RTC_HandleTypeDef hrtc;     // Defined in rtc.c
extern TIM_HandleTypeDef htim2;    // Defined in tim.c
extern UART_HandleTypeDef huart1;  // Defined in usart.c
extern UART_HandleTypeDef huart2;  // Defined in usart.c
}

int main_app() {
  /* Initialization */
  system_control::gpio_init();

  // Debug::printf("Hello %s! Count %d\n", "World", 44);

  // Initialize HV5622
  static Hv5622_driver hv_driver(&hspi1,
                                 SPI_nCS_nLE_GPIO_Port,
                                 SPI_nCS_nLE_Pin,
                                 PWM_nBL_GPIO_Port,
                                 PWM_nBL_Pin,
                                 nPOL_GPIO_Port,
                                 nPOL_Pin,
                                 Nixie_display::NUM_DRIVERS);

  // Initialize display
  static Nixie_display display(hv_driver);

  // Power up and verify things are dandy
  volatile bool power_good = system_control::power_up();

  if (!power_good) {
    system_control::power_down();
    system_control::enable_fault_led();
  }

  // Initialize time keeper, user input, and menu
  static Time_lord chronos(display, &hrtc);
  static User_input input(&htim2, ENC_PB_GPIO_Port, ENC_PB_Pin);
  static Menu menu(chronos, display);

  // Fun boot up animation?
  display.slot_machine();

  /* Super loop */
  while (true) {
    input.update();
    chronos.update();
    menu.update(input);
    display.update();
    HAL_Delay(1);
  }
}

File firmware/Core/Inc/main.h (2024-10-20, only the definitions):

#define ENC_A_Pin GPIO_PIN_0
#define ENC_A_GPIO_Port GPIOA
#define ENC_B_Pin GPIO_PIN_1
#define ENC_B_GPIO_Port GPIOA
#define UART2_VCP_TX_Pin GPIO_PIN_2
#define UART2_VCP_TX_GPIO_Port GPIOA
#define UART2_VCP_RX_Pin GPIO_PIN_3
#define UART2_VCP_RX_GPIO_Port GPIOA
#define SPI_nCS_nLE_Pin GPIO_PIN_4
#define SPI_nCS_nLE_GPIO_Port GPIOA
#define SPI_SCK_Pin GPIO_PIN_5
#define SPI_SCK_GPIO_Port GPIOA
#define PWM_nBL_Pin GPIO_PIN_6
#define PWM_nBL_GPIO_Port GPIOA
#define SPI_PICO_Pin GPIO_PIN_7
#define SPI_PICO_GPIO_Port GPIOA
#define SENSE_12V_Pin GPIO_PIN_0
#define SENSE_12V_GPIO_Port GPIOB
#define SENSE_180V_Pin GPIO_PIN_1
#define SENSE_180V_GPIO_Port GPIOB
#define BOOT1_Pin GPIO_PIN_2
#define BOOT1_GPIO_Port GPIOB
#define PG_180V_Pin GPIO_PIN_10
#define PG_180V_GPIO_Port GPIOB
#define DITHOFF_180V_Pin GPIO_PIN_11
#define DITHOFF_180V_GPIO_Port GPIOB
#define EN_180V_Pin GPIO_PIN_12
#define EN_180V_GPIO_Port GPIOB
#define ENC_PB_Pin GPIO_PIN_13
#define ENC_PB_GPIO_Port GPIOB
#define nPOL_Pin GPIO_PIN_14
#define nPOL_GPIO_Port GPIOB
#define EN_12V_Pin GPIO_PIN_15
#define EN_12V_GPIO_Port GPIOB
#define UART1_BL_TX_Pin GPIO_PIN_9
#define UART1_BL_TX_GPIO_Port GPIOA
#define UART1_BL_RX_Pin GPIO_PIN_10
#define UART1_BL_RX_GPIO_Port GPIOA
#define LED_GREEN_Pin GPIO_PIN_15
#define LED_GREEN_GPIO_Port GPIOA
#define LED_RED_Pin GPIO_PIN_4
#define LED_RED_GPIO_Port GPIOB
#define LED_BLUE_Pin GPIO_PIN_5
#define LED_BLUE_GPIO_Port GPIOB
#define SET_ILIM_Pin GPIO_PIN_6
#define SET_ILIM_GPIO_Port GPIOB
#define HW_REV2_Pin GPIO_PIN_7
#define HW_REV2_GPIO_Port GPIOB
#define HW_REV1_Pin GPIO_PIN_8
#define HW_REV1_GPIO_Port GPIOB
#define HW_REV0_Pin GPIO_PIN_9
#define HW_REV0_GPIO_Port GPIOB

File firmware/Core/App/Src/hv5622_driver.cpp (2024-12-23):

// hv5622_driver.cpp

#include "hv5622_driver.hh"

namespace {
static constexpr uint8_t BITS_PER_BYTE = 8;
static constexpr uint8_t BYTES_PER_WORD = 4;
static constexpr uint8_t BYTE_MASK = 0xFF;

static constexpr uint8_t BYTE3_SHIFT = BITS_PER_BYTE * 3;
static constexpr uint8_t BYTE2_SHIFT = BITS_PER_BYTE * 2;
static constexpr uint8_t BYTE1_SHIFT = BITS_PER_BYTE * 1;
static constexpr uint8_t BYTE0_SHIFT = 0;

}  // namespace

Hv5622_driver::Hv5622_driver(SPI_HandleTypeDef* hspi,
                             GPIO_TypeDef* nCS_port,
                             uint16_t nCS_pin,
                             GPIO_TypeDef* blanking_n_port,
                             uint16_t blanking_n_pin,
                             GPIO_TypeDef* polarity_n_port,
                             uint16_t polarity_n_pin,
                             uint8_t num_drivers)
    : hspi_(hspi),
      nCS_port_(nCS_port),
      nCS_pin_(nCS_pin),
      blanking_n_port_(blanking_n_port),
      blanking_n_pin_(blanking_n_pin),
      polarity_n_port_(polarity_n_port),
      polarity_n_pin_(polarity_n_pin),
      num_drivers_(num_drivers) {
  // Start with blanking active (low) so everything is off
  blank_outputs(true);
  invert_output_polarity(false);

  // Start with nCS high
  deselect();
}

bool Hv5622_driver::write_data(const uint32_t* data, uint8_t num_words) {
  // Check num words
  if (num_words != num_drivers_) {
    return false;
  }

  // Check data is not null
  if (!data) {
    return false;
  }

  // Data is shifted from the Shift register to the latches on logic input high.
  // Hold the latch pin (also chip select) low to load up the shift registers
  // Rising edge on latch transfers contents of shift register to the outputs
  // SPI periph will do this automatically

  select();
  // Send data for each driver
  for (uint8_t i = 0; i < num_drivers_; i++) {
    uint32_t word = data[i];

    // SPI Periph set to MSB so this will shift out starting with MSB
    // e.g. if sending a word with only MSB set high - HVOUT32 will be high and
    // all others low It's nice since the data words bits are mapped directly to
    // the (pin_name - 1) i.e bit0  -> HVOUT1 bit15 -> HVOUT16 bit31 -> HVOUT32
    uint8_t bytes[BYTES_PER_WORD] = {
        static_cast<uint8_t>((word >> BYTE3_SHIFT) & BYTE_MASK),  // MSB
        static_cast<uint8_t>((word >> BYTE2_SHIFT) & BYTE_MASK),
        static_cast<uint8_t>((word >> BYTE1_SHIFT) & BYTE_MASK),
        static_cast<uint8_t>((word >> BYTE0_SHIFT) & BYTE_MASK)};  // LSB

    HAL_StatusTypeDef status =
        HAL_SPI_Transmit(hspi_, bytes, BYTES_PER_WORD, 10);

    if (status != HAL_OK) {
      deselect();
      return false;
    }
  }

  deselect();
  return true;
}

void Hv5622_driver::blank_outputs(bool state) {
  // Active Low pin so low = blanked, high = active
  if (state) {
    HAL_GPIO_WritePin(blanking_n_port_, blanking_n_pin_, GPIO_PIN_RESET);
  } else {
    HAL_GPIO_WritePin(blanking_n_port_, blanking_n_pin_, GPIO_PIN_SET);
  }
}

void Hv5622_driver::invert_output_polarity(bool state) {
  // polarity_n low inverts all outputs (keep high for normal operation)
  if (state) {
    HAL_GPIO_WritePin(polarity_n_port_, polarity_n_pin_, GPIO_PIN_RESET);
  } else {
    HAL_GPIO_WritePin(polarity_n_port_, polarity_n_pin_, GPIO_PIN_SET);
  }
}

void Hv5622_driver::select() {
  HAL_GPIO_WritePin(nCS_port_, nCS_pin_, GPIO_PIN_RESET);
}

void Hv5622_driver::deselect() {
  HAL_GPIO_WritePin(nCS_port_, nCS_pin_, GPIO_PIN_SET);
}

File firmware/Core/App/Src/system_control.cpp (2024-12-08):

// system_control.cpp

#include "system_control.hh"

#include <cstdint>

#include "main.h"

namespace system_control {
// TODO: add analog voltage check in system control

static constexpr uint16_t DELAY_ILIM = 100;
static constexpr uint16_t DELAY_12V = 100;
static constexpr uint16_t DELAY_180V = 100;
static constexpr uint16_t DELAY_BOOT = 1000;

bool power_up() {
  // Increase the current limit of the input load switch
  HAL_GPIO_WritePin(SET_ILIM_GPIO_Port, SET_ILIM_Pin, GPIO_PIN_SET);
  HAL_Delay(DELAY_ILIM);

  // Turn on 12V rail
  enable_12v();
  HAL_Delay(DELAY_12V);  // Wait for rail to stabilize
  // TODO: read 12V rail voltage and check it looks good

  enable_180v();
  HAL_Delay(DELAY_180V);
  if (!is_180v_power_good()) {
    return false;
  }

  return true;
}

void power_down() {
  disable_180v();
  disable_12v();
}

void gpio_init() {
  disable_fault_led();
  disable_heartbeat_led();
  disable_status_led();

  HAL_Delay(DELAY_BOOT);
}

void enable_180v() {
  HAL_GPIO_WritePin(EN_180V_GPIO_Port, EN_180V_Pin, GPIO_PIN_SET);
}

void disable_180v() {
  HAL_GPIO_WritePin(EN_180V_GPIO_Port, EN_180V_Pin, GPIO_PIN_RESET);
}

void enable_12v() {
  HAL_GPIO_WritePin(EN_12V_GPIO_Port, EN_12V_Pin, GPIO_PIN_SET);
}

void disable_12v() {
  HAL_GPIO_WritePin(EN_12V_GPIO_Port, EN_12V_Pin, GPIO_PIN_RESET);
}

bool is_180v_power_good() {
  return HAL_GPIO_ReadPin(PG_180V_GPIO_Port, PG_180V_Pin) == GPIO_PIN_SET;
}

void enable_fault_led() {
  HAL_GPIO_WritePin(LED_RED_GPIO_Port, LED_RED_Pin, GPIO_PIN_RESET);
}

void disable_fault_led() {
  HAL_GPIO_WritePin(LED_RED_GPIO_Port, LED_RED_Pin, GPIO_PIN_SET);
}

void enable_heartbeat_led() {
  HAL_GPIO_WritePin(LED_BLUE_GPIO_Port, LED_BLUE_Pin, GPIO_PIN_RESET);
}

void disable_heartbeat_led() {
  HAL_GPIO_WritePin(LED_BLUE_GPIO_Port, LED_BLUE_Pin, GPIO_PIN_SET);
}

void enable_status_led() {
  HAL_GPIO_WritePin(LED_GREEN_GPIO_Port, LED_GREEN_Pin, GPIO_PIN_RESET);
}

void disable_status_led() {
  HAL_GPIO_WritePin(LED_GREEN_GPIO_Port, LED_GREEN_Pin, GPIO_PIN_SET);
}

}  // namespace system_control

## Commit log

2022-10-31 added mcu symbol
    [STM32_Nixie.kicad_sch]
2022-11-04 Added MCU page and shift register.
    [STM32_Nixie.kicad_sch, mcu.kicad_sch, shift_registers.kicad_sch]
2022-11-06 added a nixie symbol
    [STM32_Nixie.kicad_sch, nixie.kicad_sch, shift_registers.kicad_sch]
2022-11-23 updated the nixie schematic
    [STM32_Nixie.kicad_sch, nixie.kicad_sch, shift_registers.kicad_sch]
2022-11-24 wired up Nixie tubes
    [STM32_Nixie.kicad_pcb, STM32_Nixie.kicad_sch, mcu.kicad_sch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]
2022-11-26 Added level shifter and finished up HV Shift Register page
    [STM32_Nixie.kicad_sch, level_shifter.kicad_sch, mcu.kicad_sch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]
2022-11-27 Added USBC Connector to power page
    [level_shifter.kicad_sch, nixie.kicad_sch, power.kicad_sch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]
2022-12-12 added some subfolders
    [STM32_Nixie.kicad_pcb, STM32_Nixie.kicad_sch, level_shifter.kicad_sch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]
2022-12-12 Started STM32CubeIDE project
    [STM32_Nixie.kicad_sch, mcu.kicad_sch]
2022-12-26 Added MCU bypassing
    [STM32_Nixie.kicad_sch, mcu.kicad_sch]
2022-12-28 Added LSE crystal and started configuring MCU Pinout"
    [STM32_Nixie.kicad_sch, level_shifter.kicad_sch, mcu.kicad_sch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]
2022-12-29 Added 8MHz Oscillator and mapped most of the MCU pins"
    [STM32_Nixie.kicad_sch, level_shifter.kicad_sch, mcu.kicad_sch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]
2022-12-30 Added ferrite to ADC input, Coin-Cell, and STLINK conn.
    [STM32_Nixie.kicad_pcb, STM32_Nixie.kicad_sch]
2022-12-30 Added Boot mode selection
    [STM32_Nixie.kicad_sch, mcu.kicad_sch, power.kicad_sch]
2023-01-02 Changed Boot0 switch to mom. pb, added rotary encoder, and nRST pb
    [STM32_Nixie.kicad_sch, mcu.kicad_sch, power.kicad_sch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]
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2023-01-09 Added MCU pinouts for rotary encoder
    [STM32_Nixie.kicad_sch, level_shifter.kicad_sch, mcu.kicad_sch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]
2023-01-15 Added IN-3 dots, picked FTDI chip and 3.3V LDO
    [STM32_Nixie.kicad_sch, nixie_display.kicad_sch, power.kicad_sch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]
2023-01-29 added a sime of the 12V boost
    [STM32_Nixie.kicad_sch]
2023-02-03 12V boost sim in a good place with calculated values
    [STM32_Nixie.kicad_sch, power.kicad_sch]
2023-02-04 Finished 12V boost circuit and updated sim to match
    [STM32_Nixie.kicad_sch, mcu.kicad_sch, power.kicad_sch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]
2023-02-04 Updated caps on 12V Boost, added caps for 3.3V LDO
    [STM32_Nixie.kicad_sch, power.kicad_sch]
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2024-03-13 Started adding 180V boost components
    [STM32_Nixie.kicad_sch, power.kicad_sch]
2024-04-08 Added FET, shunt, and shunt filter
    [STM32_Nixie.kicad_sch, power.kicad_sch]
2024-04-14 Added Diode and output caps to 180V Boost
    [STM32_Nixie.kicad_sch, power.kicad_sch]
2024-04-16 Added soft start cap
    [STM32_Nixie.kicad_sch, power.kicad_sch]
2024-04-21 Added most of the passives for the 180V supply
    [STM32_Nixie.kicad_sch, power.kicad_sch]
2024-05-02 Added bypass caps for Bias and Vcc connection to 12V
    [STM32_Nixie.kicad_sch, power.kicad_sch]
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2024-05-12 Added snubber DNP footprints and named nets on power page.
    [STM32_Nixie.kicad_pcb, STM32_Nixie.kicad_sch, level_shifter.kicad_sch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]
2024-05-13 Added 12V and 180V sense lines
    [STM32_Nixie.kicad_sch, mcu.kicad_sch, power.kicad_sch]
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2024-07-15 Added load switch to input to limit inrush
    [STM32_Nixie.kicad_sch, level_shifter.kicad_sch, mcu.kicad_sch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]
2024-07-15 Added load swtich current limit change FET and plumbed out signals to top level
    [STM32_Nixie.kicad_sch, usb_conn.kicad_sch]
2024-07-16 Added load switch fault LED and some notes on usb esd diodes
    [STM32_Nixie.kicad_sch, usb_conn.kicad_sch]
2024-08-05 Added ESD protection to 5V input, leds, hw rev pins, and test points.
    [STM32_Nixie.kicad_sch, mcu.kicad_sch, nixie_display.kicad_sch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]
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2024-08-08 Fixed a bunch of footprints and added missing 3D models
    [STM32_Nixie.kicad_pcb, STM32_Nixie.kicad_sch, mcu.kicad_sch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]
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2024-08-11 Started layout!! 180V boost mostly laid out
    [STM32_Nixie.kicad_pcb, STM32_Nixie.kicad_sch, level_shifter.kicad_sch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]
2024-08-12 Added 180V clearance rules. Updated 0805 footprints to 1206 for 180V nets.
    [STM32_Nixie.kicad_pcb, mcu.kicad_sch, nixie.kicad_sch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]
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2024-08-18 Placement V1. Want to try and centre the board on the nixies vertically. Saving progress before trying out different placements.
    [STM32_Nixie.kicad_pcb, STM32_Nixie.kicad_sch, mcu.kicad_sch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]
2024-08-18 Liking this placement a lot better -- board is looking more symmetric north to south
    [STM32_Nixie.kicad_pcb]
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2024-08-22 Added note about mcu reset
    [mcu.kicad_sch, power.kicad_sch]
2024-09-28 Routing progress! Maybe 30% done.
    [STM32_Nixie.kicad_pcb, STM32_Nixie.kicad_sch, level_shifter.kicad_sch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]
2024-09-29 50% done routing. Power pour progress!
    [STM32_Nixie.kicad_pcb]
2024-09-29 Making progress on nixie tube signal routing
    [STM32_Nixie.kicad_pcb, nixie.kicad_sch, nixie_display.kicad_sch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]
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2024-09-30 Reshuffled nixie schematic to ease with routing. Need to fix the other 3 digits next.
    [STM32_Nixie.kicad_pcb, nixie.kicad_sch, nixie_display.kicad_sch]
2024-10-06 Reshuffled Nixie page some more to make routing cleaner
    [STM32_Nixie.kicad_pcb, nixie_display.kicad_sch]
2024-10-06 All nets routed!! (I think)
    [STM32_Nixie.kicad_pcb, nixie.kicad_sch]
2024-10-07 Ref Designators cleaned up. Started DRC squashing
    [STM32_Nixie.kicad_pcb]
2024-10-10 Added teardrops and removed unused pad shapes.
    [power.kicad_sch]
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2024-10-12 Some minor tweaks and generated gerbers
    [STM32_Nixie-B_Mask.gbs, STM32_Nixie-B_Paste.gbp, STM32_Nixie-B_Silkscreen.gbo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]
2024-10-16 Generated outputs for built round 2
    [STM32_Nixie-B_Mask.gbs, STM32_Nixie-B_Paste.gbp, STM32_Nixie-B_Silkscreen.gbo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]
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2024-11-04 Realized I got my tube naming backwards. Updated schematic with correct naming annotations
    [nixie.kicad_sch, nixie_display.kicad_sch]
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2024-12-23 Fixed encoder update bug!
    [main_app.cpp, menu.cpp, user_input.cpp]
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

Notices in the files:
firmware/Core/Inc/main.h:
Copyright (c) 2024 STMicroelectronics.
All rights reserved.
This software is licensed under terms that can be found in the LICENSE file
